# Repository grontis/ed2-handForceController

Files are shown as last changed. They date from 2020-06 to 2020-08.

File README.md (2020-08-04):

# ed2-handForceController
Engineering Design 1/2 Project for Group 9

TeamMembers:

Lillian Boettcher

Grant Kveton

Dhaval Manojkumar Shirvi

### Final Presentation Video
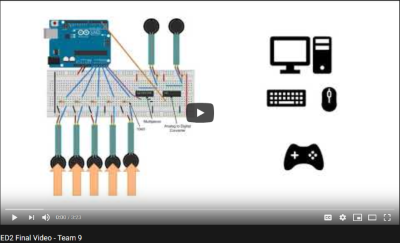
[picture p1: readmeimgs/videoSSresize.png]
finalVideo (http://www.youtube.com/watch?v=HQArYuJmiJw "ED2 Final Video - Team 9")


## HFController.cs documentation
*(as of 7/29/20, gkveton)*

#### Constructors:
HFController() - Initializes a new instance of the HFController class

#### Fields:
serialPort - System.IO.Ports.SerialPort object

serialMessage - incoming message form serial port

NUMBER_OF_SENSORS - number of sensors being read

readings - array containing sensor readings

#### Properties

IsConnected - Gets the boolean value of whether the serial port is open and connected for the device.

PortNames - Gets the array of string values for all available port names.

ConnectedPortName - Gets the string value of the port name being used for serial communication. 

#### Methods:
GetSensorValue(int sensorId) - returns sensor reading from given sensor number. 

PrintReadings() - Debugging method used to print array of readings.

ReconnectDevice() - Runs the port finding and connection algorithm.

ClosePort() - Closes the connection to the serial port for the device.

##### Example use
```
using System.Collections;
using System.Collections.Generic;
using UnityEngine;

public class CubeController : MonoBehaviour
{
    private HFController controllerInput;   
    
    // Start is called before the first frame update
    void Start()
    {
        controllerInput = new HFController();
    }

    // Update is called once per frame
    void Update()
    {
        if(controllerInput.IsConnected)
        {
            ProcessMovement();
            controllerInput.PrintReadings();
        }
        else
        {
            Debug.Log("Controller not connected");
            controllerInput.ReconnectDevice();
        }

    }
    
    private void ProcessMovement()
    {
        if (controllerInput.GetSensorValue(0) > 800)
        {
            transform.position = transform.position + new Vector3(5f * Time.deltaTime, 0, 0);
        }
        if (controllerInput.GetSensorValue(1) > 800)
        {
            cube1.transform.position = cube1.transform.position - new Vector3(5f * Time.deltaTime, 0, 0);
        }
    }
    
    private void EndSimulation
    {
        //Application exit logic here, perhaps this function is called when an "Exit" button is clicked. 
        controllerInput.ClosePort();
    }
}
```

## Serial Communication Between Arduino and Unity C# 
*(as of 7/31/20, gkveton)*

If you do not have Unity installed, install it (The unity hub is a nice way to keep track of projects and install versions, in my opinion):
https://unity3d.com/get-unity/download

If you do not have the Arduino IDE installed, install it:
https://www.arduino.cc/en/main/software

Connect force sensors and Arduino based on circuit diagram:
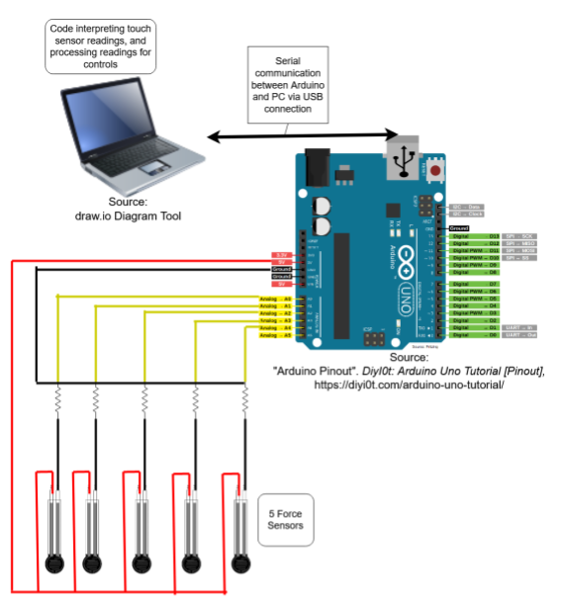
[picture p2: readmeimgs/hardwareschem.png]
proposal_hardware_schematic


Clone the project repository to your local machine:
https://github.com/grontis/ed2-handForceController

Open the "main" Arduino sketch in the Arduino IDE and upload the sketch to the Arduino:
File-> Open -> Navigate to the arduino/main folder in the cloned repo and open the Arduino file.
Make sure your Arduino is connected to USB of computer.
Sketch->Upload 
(You may need to check that your serial port for the Arduino is selected in the IDE correctly, this can be done under Tools->Port:… mine has an option for COM3(Arduino Uno))

Open the Unity project and run it to test communication:
Open the UnityHub, click “Add” and navigate to the cloned repo and select the “ed2-UnityProject” folder and click “select folder”. It is possible you may encounter that you do not have the project’s version of unity installed. If so you can click on “Installs” and install the version listed under the project (it will probably be best for us all to be working on the project in the same version since we are sharing the repository).
Open the project and in the project window in assets in the “Scenes” folder. Double click to open the “grant_3dobject_test”

This test scene involves moving 5 cubes based on 5 sensor values. Make sure that the value for NUM_OF_SENSORS is set to the correct number of sensors being used in both the HFController.cs script and the main arduino sketch.

press the play button (or CTRL+P) to start the application.
Once the scene is started in the Unity editor the script will programmatically attempt to connect to the Arduino and establish communication. This is done by sending a "wakeup" message to each of the available serial ports in the system. The main arduino sketch is programmed to await the "wakeup" message and will send a response when received. There is a mechanism of callbacks between the arduino and the software as data is transmitted. 

NOTE: When making a new Unity project (that isn’t the one setup in the repo) that will be using serial port communication, *before* creating your C# scripts you have to go into Edit-> Project Settings-> Player -> Api compatibility level and set it to “.NET 4.x”, and then restart Unity. Otherwise, the System.IO.Ports namespace will not import. From my debugging over this, I think it has something to do with the way Unity creates C# script assemblies.

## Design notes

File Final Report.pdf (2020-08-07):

1

## Hand Force Controller

A force sensing gaming and computer controller

A Proposal Submitted by Team 9

Lillian Boettcher

Grant Kveton

Dhaval Manojkumar Shirvi

Affiliations

Florida Atlantic University

Department of Engineering and Computer Science

Course: ENG 4952C - 001

Instructor: Dr. Hari Kalva

Submitted 6 August 2020

Hand Force Controller | Boettcher, Kveton, Shirvi 2

### Project Summary

Accessibility to computer functionality, gaming, and virtual reality is becoming more

demanding as technology advances further and more people are using these devices and

technologies. Many devices exist for controlling computer and game commands, most popularly

a computer keyboard and mouse as well as certain specialized gaming controllers. For virtual

reality, controllers are moved in real life and translate to movements in a virtual space using

internal accelerometers and gyroscopes. These have limitations for some individuals, primarily

in how they often require excessive movement. There are some controllers made for people who

have difficulty moving their hands or limbs effectively enough to use these devices, but they

normally consist of additional buttons and still require a large level of movement.

The Hand Force Controller is a proposed device to solve this problem by using force

sensors to read subtle amounts of force in a user’s fingertips and throughout their hand. The

force needed to use the controller can be specified through user calibration. Additionally, the

sensors can be moved around to however the user finds them most comfortable. Therefore, the

Hand Force Controller is a stationary controller that can be specialized to how the user wants the

layout and how much force they want to apply in order to use it. The controller comes with an

application that is straightforward to use, a 3D printable platform that can be customized to the

user’s preferences, and a user manual. The software application has quick calibration settings

and a simple interface for accessing other functionality. To demonstrate how it can be used in

gaming and virtual reality, there are two game demos, a first-person shooter game and a playable

virtual piano. As part of the main functionality, there is a program for setting different controller

gestures to different keyboard commands so the controller can emulate any computer game.

Thus, the Hand Force Controller is a combination of hardware and software to present a

specialized gaming controller and keyboard emulator.

(Boettcher)

### Table of Contents

Project Summary | 2
Introduction | 7
Background | 7
Problem Statement | 8
Scope of Work | 9
Overview | 9
Design Stage | 9
Hardware Implementation Stage | 9
Software Implementation Stage | 10
Final Interface Implementation and Testing | 11
Literature Review | 11
Alternative Solutions | 14
Evaluation | 16
Decision | 16
Problem Implementation Plan | 18
Research | 18
Design | 18
Image 1: Platform Model with Combined Components | 19
Deliverables | 20
Tasks | 21
Figure 1: Task Division Diagram | 23
Prototype Construction | 23
Image 2: Hardware Prototype | 24

Implementation Details | 25
System Specifications and Functionality | 25
System Design | 26
Figure 2: Overall System Design Diagram | 27
Hardware Subsystem Design | 27
Figure 3: Circuit Diagram | 29
Serial Communication Subsystem Design | 29
Figure 4: HFController Variables and Functions | 31
Piano Simulation Subsystem Design | 31
Image 3: Piano Simulation View | 32
Figure 5: Piano Simulation Use-Case Diagram | 34
Keyboard Emulation Subsystem Design | 34
Image 4: Keyboard Emulation Settings | 35
Figure 6: Keyboard Emulation Use-Case Diagram | 36
First-Person Shooter Game Subsystem Design | 36
Image 5: First-Person Shooter View | 37
Figure 7: First-Person Shooter Game Use-Case Diagram | 38
Testing Results | 38
Table 1: Serial Communication Testing Outline | 39
Discussion on Lessons Learned | 40
Conclusion | 42
References | 43
Organization Chart | 45
Figure 8: Organization Chart | 45
Budget | 46

Table 2: Projet Budget | 46
Appendices | 47
Hardware Schematics | 47
Figure 9: Circuit Diagram | 47
Program Schematics | 48
Figure 10: Serial Communication Pseudocode Schematic | 48
Figure 11: Application Main Screen UI Design | 49
Figure 12: Calibration Activity Diagram | 49
Figure 13: Keyboard Emulation Activity Diagram | 50
Figure 14: Piano Simulation Activity Diagram | 50
Figure 15: First-Person Shooter Game Activity Diagram | 51

### Introduction

Background

Controlling computer software originally uses a simple keyboard and mouse to maneuver

selecting system objects and typing documents and commands. However, with an increase in the

complexity of computer gaming and virtual reality (VR), specialized computer controllers are

now often used for different games with different playstyles. These controllers require the user’s

hands to be in different positions and perform different positions. Many controllers use large

movements of joysticks or the controllers themselves through motion sensing, which can allow

for more immersive experiences or more possible ways to control game actions.

These controllers vary greatly and are continuously in demand as the number of people

who play games and perform various computerized tasks increases and as controller and game

technology advances. These controllers are mainly geared towards people who are passionate

towards gaming and VR and want more immersive or specialized control in their games or

simulations. However, some controllers exist for people with disabilities, such as a loss of limbs

or trouble with movement, which allows people with physical disorders to control computer

commands and participate in gaming.

(Boettcher)

Problem Statement

While there are some gaming controllers for people who have physical disabilities, they

are primarily geared towards people who have amputated limbs or distorted figures. There are few controllers for people who have trouble with simple movements, such as rapidly moving

their fingers up and down, which is required on nearly all types of gaming devices. For virtual

reality in particular, there is little in the way of controllers that do not require large limb

movements, since VR uses movements in real life to translate to movements in a virtual

environment. Because of this, controllers do not largely exist for VR for disabled people who

cannot move well enough to use VR controllers and equipment. Therefore, while there are

people who need special devices for playing computer games without having to perform

excessive movements, especially for VR simulations, there are few controllers that have proven

effective enough to be a solution for these individuals.

(Boettcher)

### Scope of Work

Overview

### 1. Design Stage

The Hand Force Controller begins with an initial design stage that involves researching

what components will be needed to accomplish the goals of the initial idea. The design stage

proved to be an iterative process as the team finalized the system requirements in the original

proposal document and determined what components would be best suited for the project. The

initial hardware design involves developing circuit diagrams based on research, so the

components can be quickly assembled and tested when received. Software libraries and tools are

researched in this stage to determine a practical design and implementation of the desired

software applications to be delivered with the controller. The list of hardware components is

finalized for the project budget and confirmed to be ordered.

(Kveton)

### 2. Hardware Implementation Stage

The hardware implementation stage begins once the hardware components have been

ordered and received. The hardware implementation takes a bottom-up approach in that the

complexity of the project increases as more components are implemented and tested. The first

stage involves configuring a single sensor and having values read by the Arduino

microcontroller. The second stage involves configuring multiple sensors to be read by the

Arduino. The final stage of the hardware implementation occurs when the number of sensors exceeds the number of analog inputs available on the Arduino microcontroller. A multiplexer is

implemented in this final stage to allow for a greater number of sensors to be used.

(Kveton)

### 3. Software Implementation Stage

The first stage of the software implementation is the programming and testing of serial

communication between the Arduino microcontroller and the computer running the applications

created in Unity. Similar to the hardware implementation, this stage takes a bottom-up approach

by iteratively introducing and testing new components. First, the communication between

devices is tested without using any sensors. Once the communication is established, the system

for transmitting the sensor data can be implemented. The other software applications in the

project are heavily dependent on this component. Therefore, testing various use cases and

handling errors is very important.

The second stage of the software implementation involves programming the three demo

simulations that are used to demonstrate the Hand Force Controller’s capabilities. These three

applications have been divided up between the team such that each team member has an

application to work on. The keyboard command simulation and the piano simulation were

decided upon in the early design stages for the project. The idea to include a demo video game

was decided upon later in the project during progress update discussions with the professor.

Another aspect of this stage in the software implementation is the sensor calibration system. This

is designed to be implemented in a way such that it can be used in the demo applications.

(Kveton)

### 4. Final Interface Implementation and Testing

Once each of the software subsystems have been implemented and tested on their own,

they are connected together by an interface within one Unity project. This stage also involves

final testing of the entire system with all of the subsystems connected to the main screen

interface. The development testing of each subsystem on their own should allow for simplified

integration into the main system interface.

(Kveton)

Literature Review

Team Member Reviewing: Lillian Boettcher

Title: “The Human Controller: Usability and Accessibility in Video Game Interfaces”

This paper focuses on analyzing current availability of accessibility in gaming controllers

and why there is a need for an increase in accessibility. It addresses an initial fact that there are

concerns, such as cost concerns, related to providing accessibility and having all controllers

require a large amount of accessibility is not practical or feasible. Despite this, it points out that

there is an existing demand for accessible controllers and that there are people who develop

disorders, including gamers, as they age or go through life, covering aspects of the demand. It

evaluates case studies to determine possible strategies for going about creating accessibility in

places where it is lacking.

The ideas on how to improve upon current lacking technologies for the physically

impaired gives insight into specific tasks our project should accomplish. More specifically, it

stresses that there is little in the way of easy to use controllers for the physically disabled. These constraints would need to be met by creating a device that requires minimal movement and

difficult performing any required movements, which is the key focus of this project.

Team Member Reviewing: Lillian Boettcher

Title: “Game Not Over: Accessibility Issues in Video Games”

This paper covers the scope of which accessibility for games is in demand. It covers both

physical and mental aspects of where games may lack accessibility, from not providing subtitles

to follow along to audio to not being able to use the controllers that a game console requires.

These issues stem from disabilities in four different categories: visual disabilities, auditory

disabilities, mobility disabilities, and cognitive disabilities.

The Hand Force Controller relates to the third addressed disability category: mobility

disabilities. It supports the need for accessibility controllers by relaying statistics on how 12.1%

percent of the population has some sort of mobility disability. It also addresses that there are

individuals who may play games and want to continue after receiving these abilities from aging

or injury, the most common causes of these types of disorders, further proving the presence that

this is a problem with a demand for a solution.

Team Member Reviewing: Grant Kveton

Title: HandNavigator: “Hands-on Interaction for Desktop Virtual Reality”

This paper presents an innovative interactive system for controlling digital models using

hand gestures. The physical interaction device is utilizing force sensors to measure finger and

palm gestures which are then translated into software actions, similar to the Hand Force

Controller. The physical interaction device uses forces exerted from the palm and fingers to

control a virtual hand model, rather than measuring real hand movements and gestures. The

paper discusses the necessity of implementing plausible real-time interactions with the virtual

hand to enhance the user’s immersion. This is done by correctly mapping the physical device to a

well designed virtual hand model. Visual feedback, when done properly, can give the user the

perception that they are actually touching virtual objects.

Team Member Reviewing: Grant Kveton

Title: “Game Console Controller Interface for People with Disability”

This paper proposes an interface device to allow people with upper limb disabilities to

play console video games. Currently, there are few devices that address the difficulties disabled

users encounter when attempting to play video games. As video games have become more

complex, the more challenging it has become for users with disabilities to play using traditional

controllers. The device introduced in the paper seeks to implement an entirely new interface

device that uses off-the-shelf sensors and switches that can be used by disabled users to play

video games on a traditional console. The paper also describes the implementation of a method

for the user to customize the mapping of sensors to joypad pushbuttons, a similar feature to the

Hand Force Controller’s custom keyboard input subsystem. Another similar system requirement

to the Hand Force Controller is that the interface device must allow a simple setup procedure,

allowing the user to utilize the device with various applications.

Team Member Reviewing: Dhaval Manojkumar Shirvi

Title: “Evolution of Game Controllers: Toward the Support of Gamers with Physical

Disabilities”

This paper focuses on the limited consideration for players with physical disability

throughout the evolution of game controllers. It covers the disadvantage the gamers with

physical disability such as limited mobility, dexterity or a missing limb or part of the limb have

when using the standard controllers. It also covers some of the modified controllers that reduces

the disadvantage on the physically disabled players. However, the modified controllers are made

considering the players with a missing limb.

The Hand Force Controller answers the issue for the players with limited mobility or

dexterity. The controller was designed considering the players with limited mobility. And since,

the controller does not require hand movement except for exerting slight pressure, it could be a

potential solution for players with limited mobility or dexterity.

Alternative Solutions

There are many alternative approaches to VR controllers but there are not many that

require minimal movement. Currently many VR technologies use touch sensors in their

controllers. Most touch sensors use digital output, which is high if touched or low if not.

However, some touch sensors have the capability to output analog value. Even so, the VR touch

sensor controllers require hand movement. Another alternative to force sensors could be flex

sensors. The flex sensors measure the deflection or bending, which can be one of the most effective sensors for the immersive VR experience. The flex sensor might be a good approach for

immersive VR controllers, but it still requires hand movement. Although, it might not require as

much movement as touch sensors.

One of the most important hardware components is the microcontroller board. A

microcontroller board reads the values from the sensors and sends it to the computer. There are

many Arduino boards that have the same functionality, such as Arduino Leonardo and Arduino

micro. Arduino Leonardo and micro are also compatible with the keyboard library of the

Arduino. Arduino Leonardo and micro boards come with 12 analog pins (Arduino). However,

both boards are a bit advanced for beginners.

For the software aspect, creating an application for the user to test the functionality of the

controller, can be achieved on almost any platform. For example, the unreal engine by epic

games and using python executable directly. The unreal engine uses C++ scripts for the

applications, which has a method to simulate a key press. The unreal engine also provides high

quality visuals (Unreal Engine). Although the keyboard simulation only works on Windows OS

and unreal engine requires a high powered PC to run the applications due to the high-quality

visuals. On the other end python has the keyboard library and can also be used to create an

application for the user (Python). However, the application would not be very user friendly.

(Shirvi)

Evaluation

The main concept behind the Hand Force Controller is to minimize the hand movement

of the user while performing in-game actions. The force sensors have great potential to achieve

the goal, since it only requires for the user to exert a small amount of pressure. The other sensors

such as touch and the flex sensors require some hand movement to perform actions. Therefore,

the force sensor is a more preferable choice, since it requires the least amount of movement of all

the three sensors. The Arduino Uno is the base model of some of the other Arduino boards.

Arduino uno in comparison to Arduino Leonardo and Arduino micro, has less functionality but

Arduino Uno is more beginner friendly than the other two boards. Even though Unity might not

have high quality visuals or a keyboard simulation functionality, it would be the best choice for

making a user friendly application which can be run on a low end PC. And to achieve the

keyboard simulation functionality, ironpython can be used to execute python commands from cs

script. Therefore, unity makes an ideal choice for this project.

(Shirvi)

Decision

Many physically challenged could benefit from a new type of controller with another

level in how easy it is to use. To make an effective controller that allows individuals who are

physically disabled, the main factor requirements the controller needs is ease of use by

minimizing required movement. This could be done by using force sensors to detect small and

weak amounts of pressure in a user’s hand, which could be customly placed around an

individual’s hand. Additionally, to maximize accessibility, it should be held in an open-source repository that developers and users can easily access, have an adjustable platform and

calibration, and have clear instructions and examples on how to use it.

(Boettcher)

### Problem Implementation Plan

Research

The Arduino programming documentation was researched during the early stages of

design and implementation to design software functionality necessary for meeting the functional

requirements (Arduino). The analogRead() function allows the Arduino sketch to read values

from the analog force sensors connected to the analog input pins. The Serial object contains

functions related to the implementation of the serial communication, such as the println()

function and the readStringUntil() function.

The official C# documentation from Microsoft was researched during the early stages of

design and implementation to design software functionality for serial communication in Unity

(Microsoft). Specifically, the SerialPort class in the System.IO.Ports namespace was researched.

Similar to the Arduino Serial object, this class includes functions for opening the serial port

connection, reading from the serial port buffer, and writing to the serial port buffer. Code

examples in the documentation were studied for understanding of the SerialPort class but were

not used in the implementation of the project.

(Kveton)

Design

The initial design of the project included an Arduino Uno for utilizing five force sensors,

one for each finger. The design was later changed to incorporate three more force sensors. Since

the Arduino Uno only has six analog input pins, a multiplexer chip was added for the extra sensors to connect to the Arduino. This design increases the ability of the Hand Force Controller

to take into account a majority of basic hand movements. The first five force sensors are for each

finger and the extra three force sensors are for the palm, the left palm, the right palm and the

back of the hand. These sensors are to be placed on an adjustable platform comfortably position

the sensors around the user’s hand.

The platform design involves three components: the finger and thumb components, which

are used for resting the finger and thumb while using the controller, and a base. Each finger rests

on four finger components and the thumb component is used for the thumb. As the finger and

thumb components are used for resting fingers and thumb, the base platform can be used to rest

the palm of the user’s hand. The base platform has space underneath it, for placing the Arduino

Uno, and has space for force sensors to rest on the finger and thumb components. The finger and

thumb components also have slits for the force sensor wires to pass through and be placed on top

of the components so that the wires can be out of the way of the user’s fingers.

Image 1: Platform Model with Combined Components

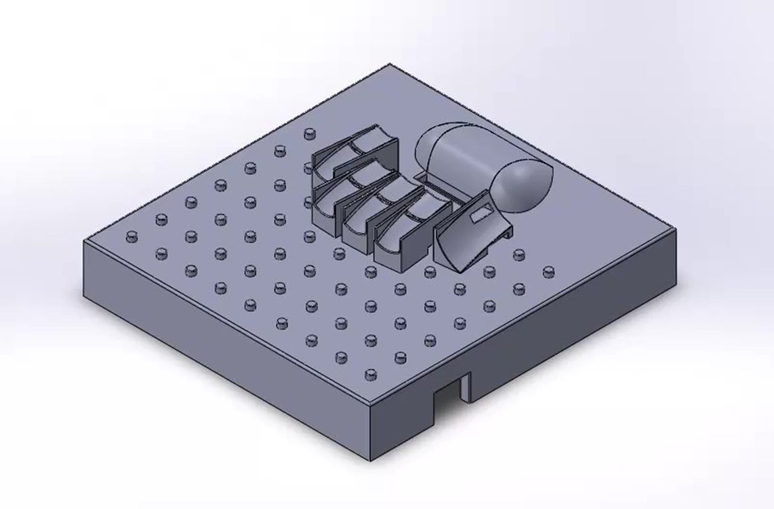
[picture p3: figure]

The Hand Force Controller can be tested on its application, which includes calibration

settings, a piano simulation, a keyboard emulator, and a first person shooter game. In the piano simulation, the Hand Force Controller can be used to play piano in a top view. The piano

simulation can be converted to VR simulation by connecting a VR headset to the camera display.

The keyboard emulator enables the Hand Force Controller to emulate keyboard keys and

commands. This allows the user to use the Hand Force Controller on any application. The first

person shooter game can be used to test the Hand Force Controller’s ability to play a common

style of computer game.

(Shirvi)

Deliverables

The project deliverables include:

- The Application
- Calibration
- The Piano Simulation
- The Keyboard Emulator
- First Person Shooter game
- Printable 3D modeled platform
- Base platform
- Finger component
- Thumb component
- Instruction manual
- Repository for the deliverables
- Hardware design

The application includes the piano simulation, the keyboard emulator and the first person

shooter that demonstrates different functionalities of the Hand Force Controller. The 3D modeled

platform includes three components one is the base platform, one is finger and the last one is

thumb. The instruction manual is a detailed step by step guide for assembling the hardware and

the 3D modeled platform. The manual also includes a guide for using the application. The

repository is for development purposes and to download the application, printable 3D platform

and the instruction manual. The hardware components include all the hardware components

required for assembling the Hand Force Controller.

(Shirvi)

Tasks

The project was given tasks that are designed to finish the project with all of the

functional and nonfunctional requirements. The simplified task division is listed below in a

diagram. These tasks were originally made to allow us to divide the work between group

members and calculate how much work we have done and how much we had left. The following

is a list of tasks and the team member leading in completing the task:

- Gather all hardware components (all)
- Design hardware (all)
- Manage an accessible repository for the application, code, and development materials

(Kveton)

- Create a user manual that gives instructions on how to use the Hand Force Controller and

replicate our work (Boettcher)

- Model components for a 3D printable platform (Shirvi)
- Main application:
- Create a main application display (Boettcher)
- Create calibration system (Boettcher)
- Create navigation to other parts of software (Boettcher)
- Consolidate all parts of the application and deploy as executable (Kveton)
- Keyboard emulator (Shirvi):
- Create a UI for emulation settings (Shirvi)
- Create script for saving emulation settings on play (Shirvi)
- Program active emulation script in Python using saved settings (Shirvi)
- Program Python receiving of sensor values from Arduino (Kveton)
- Piano simulation (Boettcher):
- Model a 3D piano asset (Boettcher)
- Connect audio files to piano keys (Boettcher)
- Script piano playing functionality based on saved calibration (Boettcher)
- First-Person Shooter Game (Kveton):
- Gather assets to form game scene (Kveton)
- Program player movement and actions based on calibration and HFController

settings (Kveton)

- Program enemy intelligence (Kveton)
- Program health and ammo systems (Kveton)

(Boettcher)

Figure 1: Task Division Diagram

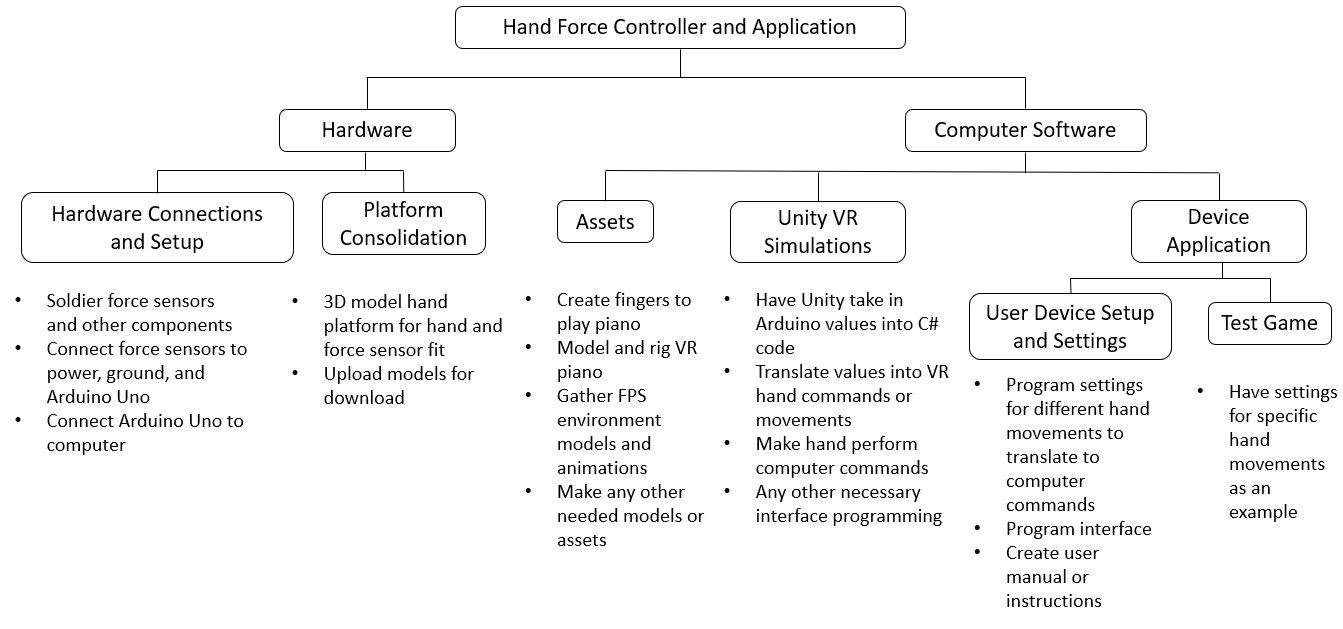
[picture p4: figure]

Prototype Construction

The complete initial prototype consists of eight force sensors to portray the complete

functionality. However, the 3D modeled platform is not a necessity for playing the simulations

created, calibration, or using the Hand Force Controller as a keyboard emulator. Therefore, the

platform was not printed and used for the initial prototype.

The initial prototype uses a running Arduino with a USB cable to print to a computer.

The model could be made using another form of connection, however, such as a Bluetooth

adapter. All eight force sensors are connected to the five-volt power supply from the Arduino

and a ground. Before the ground, however, there is a resistor for each sensor in order to allow

the sensors to read the pins. The initial prototype uses 10 kilo ohm resistors for the specific

sensors used in the prototype, but the design allows for other types of force sensors, which may

require different level resistors. In order to increase the analog inputs in the Arduino Uno, a

multiplexer is used. This is gone into more detail in the hardware section.

The prototype had no issues in terms of calibration, lag, or other common problems

known with prototypes. For future modifications in improving the Hand Force Controller, more

force sensors can be added for more control over software and allowing more possible gestures.

In addition, more platform models could be made to be more effective for different individuals

and possibly easier assembly. Parts could also be more specialized; the jumpers used in the

prototype make it different to consolidate the hardware and better hardware components could

probably be found.

(Boettcher)

Image 2: Hardware Prototype

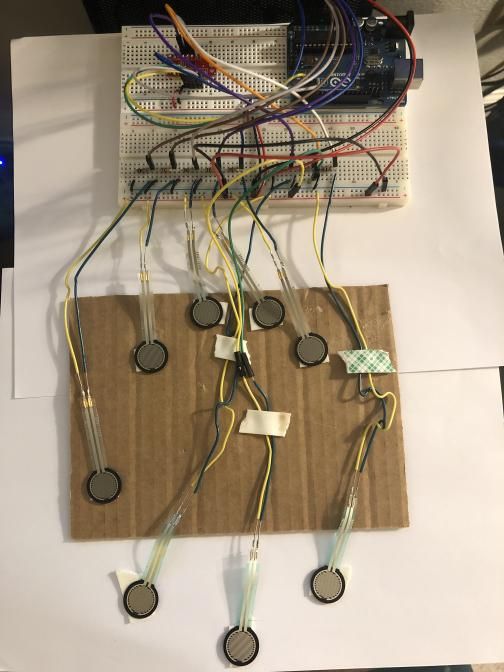
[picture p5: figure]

### Implementation Details

System Specifications and Functionality

The original functional and non-functional requirements were all generally met at the

conclusion of the project. There were no requirements officially added to the project, but the

project came to have more of a focus on also demonstrating more capabilities of the Hand Force

Controller, meaning the first non-functional requirement became more significant as

demonstrating the controller’s use became an important part of the project.

Functional Requirements

1. The system shall measure the force exerted by each finger of a human hand as an

increasing or decreasing analog value.

2. The system shall quickly and accurately transfer analog data from an Arduino

microcontroller to a computer.

3. The system shall be able to translate different analog inputs into different computer

keyboard commands.

4. The system shall be able to recognize different finger force patterns to translate into

commands or actions.

5. The system shall be implemented in such a way that there are minimal dependencies

required during setup when using the controller for different applications.

6. The physical platform for the controller shall include design and functionality that

accounts for varying hand sizes between users.

Nonfunctional Requirements

1. The product shall include an application for users to test the product.
2. The product shall include a manual or guideline for users.

(Boettcher, Kveton)

System Design

The overall system can be divided into two categories: a hardware subsystem and a

software system. The hardware system forms the Arduino Uno, force sensors, and their

hardware connections. The software consists of a Github repository containing a user manual,

3D model platform components for 3D printing, and an application. The Hand Force Controller

application can be divided into four parts: the main screen, which is where calibration and scene

navigation takes place, a keyboard emulator, a piano simulation, and a first-person shooter game.

(Boettcher)

Figure 2: Overall System Design Diagram

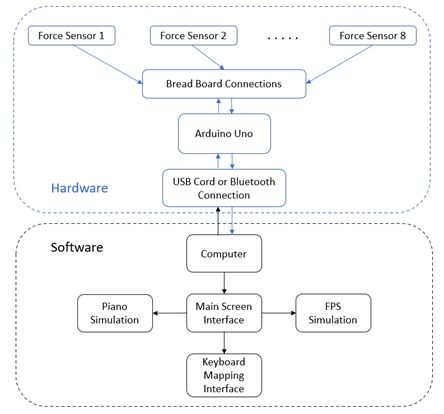
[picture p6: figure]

Hardware Subsystem Design

The microcontroller used in this project is the Arduino Uno Rev3 model. The project uses

all six analog inputs for the purpose of reading sensor input data. Five analog inputs are directly

connected to force sensors. The remaining analog input is connected to the common output pin

of the multiplexer. Three of the digital pins are connected to the select pins of the multiplexer

and are set to output values for determining which individual input pin of the multiplexer is to be

read from. The Arduino microcontroller has a USB type B port where the Arduino is connected

to a PC via USB cable, and this port is the connection in which the serial data communication

occurs.

Force Sensitive Resistors (FSR) are thin sensors that detect physical pressure upon the

sensor. As one applies pressure to the force sensor the resistance goes down and a measurement is given based on the change in resistance (Adafruit). The range of values for the force sensors in

this project was from 0 to about 1000, with 0 representing no force applied and 1000

representing a large amount of force applied.

Due to the limitations of the Arduino’s amount of analog input pins, it was necessary to

implement a multiplexer into the hardware design once the project began using more than six

force sensors. The multiplexer used in this project is the 74HC4051 eight-channel multiplexer

breakout. A multiplexer is able to iterate over its individual input pins by using three “select”

pins to determine which pin’s data will be output. The “select” pins are connected to the digital

output pins of the Arduino. The multiplexer has 8 individual input pins, and these are selected by

outputting their corresponding binary values to the “select” pins. For example, if the input pin Y1

is to be selected, then the digital pins would output “LOW, LOW, HIGH” which could also be

interpreted as the binary value 001 . The multiplexer has a common output pin that is connected

to an analog input pin of the Arduino where the currently selected input’s data is sent (SparkFun

Electronics).

(Kveton)

Figure 3: Circuit Diagram

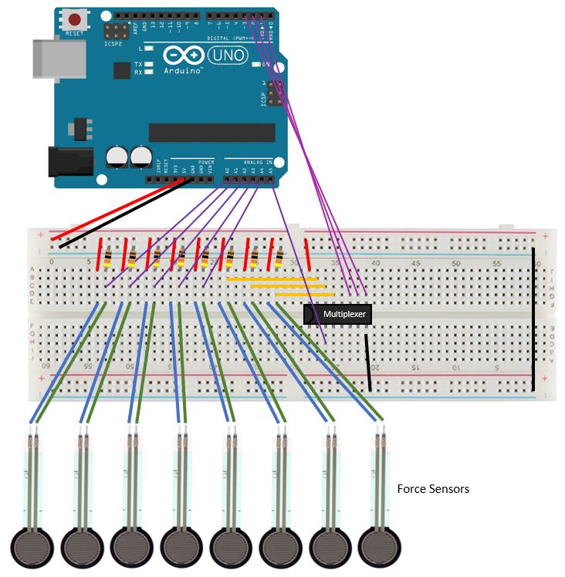
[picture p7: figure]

Serial Communication Subsystem Design

The Arduino microcontroller writes data being read from the force sensors to a serial port

buffer. A C# class in the Unity game engine, called HFController, then reads the incoming data

from the serial port buffer. This system was first implemented and tested by writing dummy data

to the serial port to be read by the HFController class on the receiving computer. Once the

communication had been established and tested, the sensor data could be used in communication.

The sensor readings for each loop within the Arduino code were packaged in a data structure of

comma separated values. The packets of readings were then written to the serial port buffer. The

packet data structure required a parsing algorithm to be designed within the C# code to unpack

the string of comma separated values to be stored in a local array. A public method for the

HFController class, GetSensorValue(int sensorId), was developed to return the current reading

for a given sensor number.

In the early stages of development, the port name was hardcoded into the Unity C# code.

An issue with this implementation is that various machines may have differently named serial

ports when the Arduino is connected to the PC. An algorithm was developed to iterate between

all available ports on the computer, sending a “wake up” message to the port. The Arduino code

is configured to wait for the “wake up” message and will send a response message when it is

received. When the C# code receives the response, it will keep that port open for communication.

There is also a timeout mechanism in place so that the Arduino will go back to its sleep state,

awaiting the “wake up” message, if it does not receive a “reading” message from the serial port

after the timeout value has passed. In the later stages of development, a public method for the

HFController class, ClosePort(), was needed to close ports as the main interface switched

between demo applications. The HFController class and the Arduino sketch are programmed

such that only the NUM_OF_SENSORS constant needs to be changed when adding more

sensors to the system.

The HFController C# class is designed in such a way that it abstracts the serial

communication and can be used modularly within various applications. The figure below shows

the fields, properties, and methods for the HFController class. The class is also documented in

greater detail in the readme of the project’s GitHub repository.

(Kveton)

Figure 4: HFController Class Variables and Functions

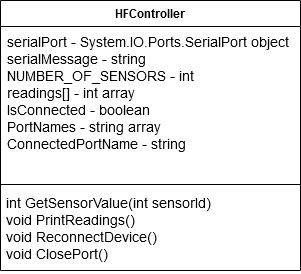
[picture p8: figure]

Piano Simulation Subsystem Design

The piano simulation is designed to demonstrate the functionality of the Hand Force

Controller to work for playing a computer simulation or virtual reality game. The game can

simply be played in a first-person view, with the camera at an orthogonal top view, but the

camera view can be adjusted to be controlled in respect to a VR headset, turning it into a VR

simulation.

The simulation is played using all eight of the force sensors. The first five force sensors

(sensors 0-4) correspond to the first five fingers of the human hand. The controller only has a

single hand and uses differently colored capsule models to represent fingers that can press keys,

so the user can use their right or left hand to control the virtual fingers. Therefore, the fingers are

referred to by number and color instead of the name of the finger, with finger 1 colored red, finger 2 colored orange, finger 3 colored yellow, finger 4 colored green, and finger 5 colored

blue.

Image 3: Piano Simulation View

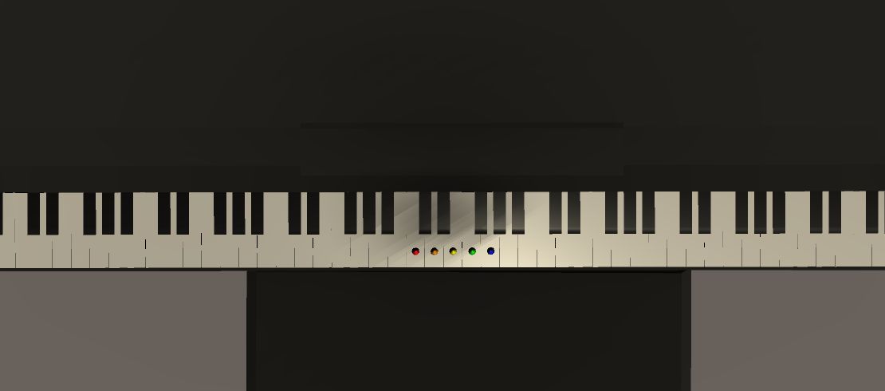
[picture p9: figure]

Force sensors 5 and 6 control the left and right movement of the fingers, respectively.

The last force sensor, sensor 7, is used to move the fingers forward towards the black keys on the

piano. Keys are pressed by pressing the first five force sensors. The amount of force needed to

press the notes for each finger is defined by the calibration in the previous main screen. This

also applies to the amount of force to activate left, right, and forward movement for the

remaining three sensors.

Key pressing is recognized by the location of each finger. For each finger, the simulation

programming checks for the position of the finger. The x and z coordinates give the position of

the keys, which are saved in array variables. These coordinates are checked for each finger,

which defines what key can be pressed. The value of the finger force sensors define the y

coordinate position of the fingers. If the finger is lowered to a certain degree, the note at its

position is activated. An activated note changes color and plays its corresponding audio file. A

white note will change to pink while activate and black notes to purple. When the position of the finger changes to a different note through a change in the x or z coordinates or when the y

coordinates are raised above a certain threshold, the note audio that was previously playing stops.

The x coordinates of all of the fingers, as well as the camera, are changed using sensors 5

and 6. When sensor 5 is pressed to a value above its calibration value, each finger and the

camera move left, or across the negative x-axis, a specific degree each frame update. The

amount is defined by the degree to which the sensor value is greater than the calibration value.

The same applies to force sensor 6, except it creates right movement when pressed across the

positive x-axis.

Force sensor 7 moves all of the fingers forward on the z-axis, which allows the black

keys to be playable. When the sensor value is above the calibration value for sensor 7, the

fingers all move forward. The amount moved per frame is, like with the left and right

movements, defined by the amount the sensor value is larger than the calibration value. When

the sensor value is lower than the calibration value, the fingers move backwards towards the

white key only region (where black keys cannot be reached or played along the x-axis).

(Boettcher)

Figure 5: Piano Simulation Use-Case Diagram

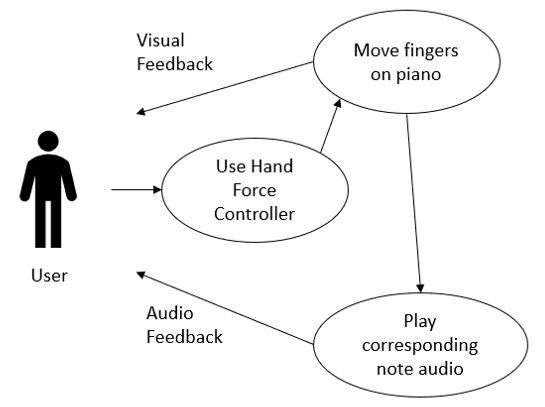
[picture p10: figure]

Keyboard Emulation Subsystem Design

The keyboard emulation program is designed to turn the Hand Force Controller into an

emulator for any computer application. The main purpose of the keyboard emulation subsystem

is to be able use the Hand Force Controller to play different video games, though it can be used

on other applications as well.

The keyboard emulation program uses different gestures that can be performed on the

Hand Force Controller to emulate different keyboard commands. The gestures include the

individual eight force sensors and combinations of the first five force sensors. All the gestures

are available to be viewed on the keyboard command screen. The gestures are simple and self

explanatory. Eight of the available gestures correspond to the eight force sensors. The

combination of the first five force sensors (for each finger) can be used for combinational

gestures. A key or a command can be assigned to each available gesture on the keyboard

command screen. It is mandatory to assign keys to the eight individual gestures, however assigning a key to the combinational gestures is optional. A play button can be pressed when the

user is done assigning the keys or gestures.

Image 4: Keyboard Emulation Settings

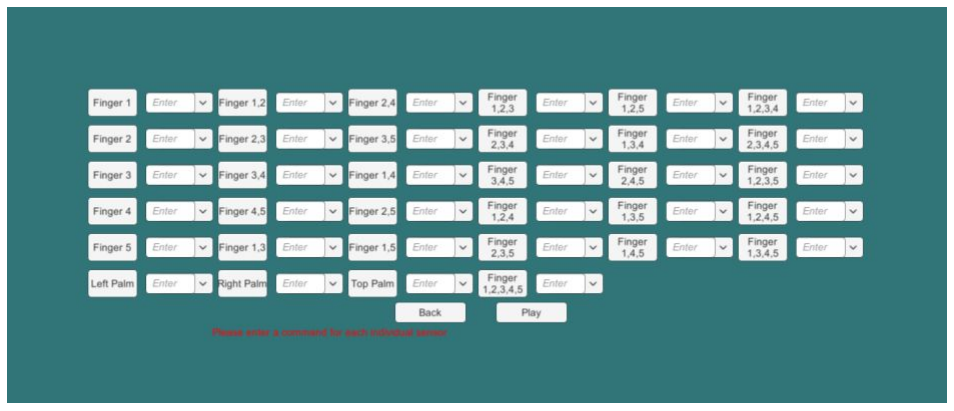
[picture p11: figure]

Once the play button is clicked, the assigned keys and the port name are saved to a text

file and a Python script is executed using IronPython. IronPython allows C sharp scripts to

execute or use Python commands. The Python script reads the keys and the port name from the

text file using an open() function. The port name is then used to connect to the Arduino via a

serial library. The Python script also uses the keyboard library to simulate key pressing. The keys

read from the file are used by the keyboard.press() function, which performs key presses. The

values of the force sensors are constantly being read in a main loop from the Arduino by the

Python serial library. Every time one of the gestures is performed on the controller and the

reading is above a certain threshold, based on saved calibration values, the key assigned to each

respective gesture is pressed.

(Shirvi)

Figure 6: Keyboard Command Use-Case Diagram

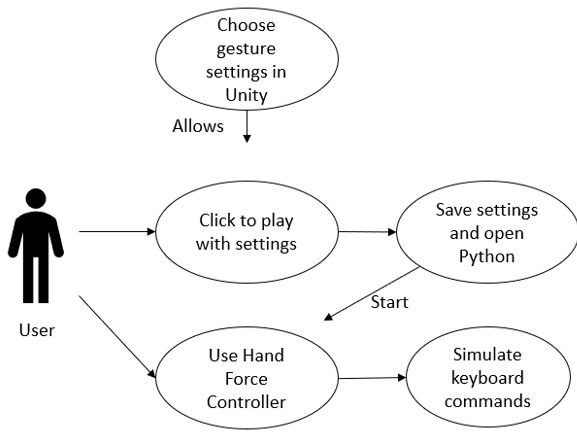
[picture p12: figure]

First-Person Shooter Game Subsystem Design

In the early stages of design and implementation, it was suggested to the team by the

professor that an open source video game would be an interesting and effective way to

demonstrate the capabilities of the Hand Force Controller. A team member was currently

working on an online tutorial course for game development in Unity that could be used as an

example application (Tristem and Davidson). A video game developed within the team was

beneficial to the project’s time scope because the source code was more familiar compared to an

unfamiliar open source project. The zombie first person shooter (FPS) game was developed in

this tutorial course and used free art assets provided with the course and from the Unity asset

store. The integration of the Hand Force Controller into this demo game is an example of the

Hand Force Controller being implemented directly into a video game by the developer.

Image 5: First-Person Shooter View

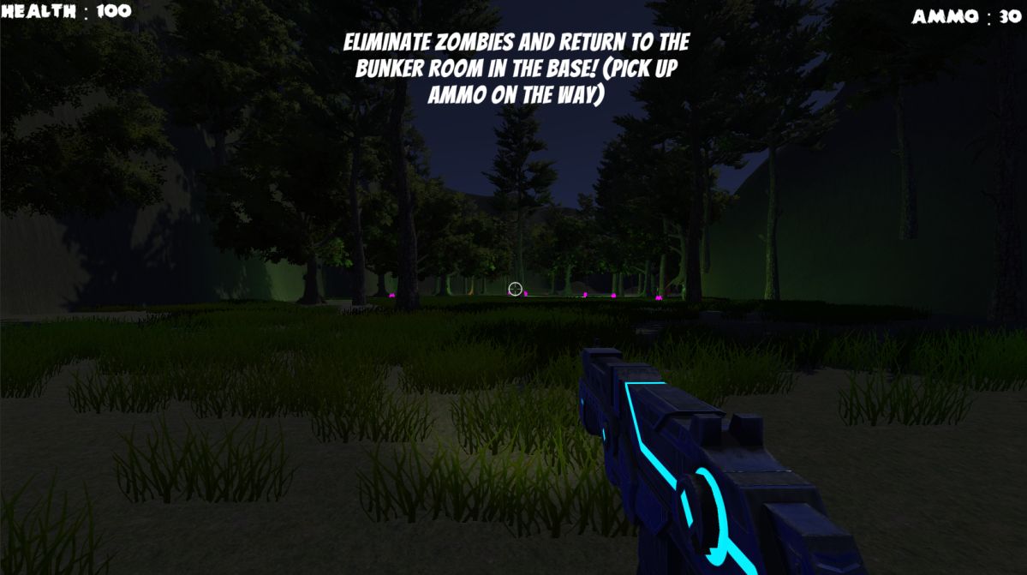
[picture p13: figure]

The HFController class is used in the FPS game within a configuration script to map

game actions to the Hand Force Controller. Implementing the HFController this way allows for

the programmer to abstract the HFController logic from the rest of the game. For example, in the

HFConfig script the “moveForward” action may be mapped to sensor 2, and therefore, another

script that contains the logic to move forward only has to reference the HFConfig.moveForward

field and not the actual sensor ID. Controller calibration is implemented in the FPS demo such

that the calibration values are retrieved from the Unity PlayerPrefs object and are used as a

resting threshold for the sensors.

(Kveton)

Figure 7: First-Person Shooter Game Use-Case Diagram

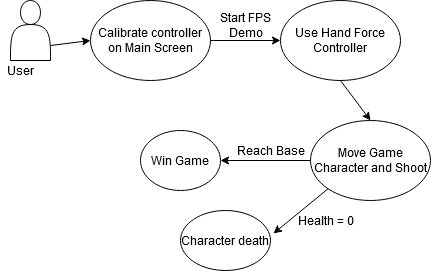
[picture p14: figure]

Testing Results

The serial communication subsystem is the most tested subsystem in the project because

every other subsystem is dependent on the communication functioning properly. The testing of

this subsystem was performed using a unit testing approach to verify functionality of the various

components within the subsystem. As each component of the subsystem was implemented it was

tested to meet the necessary functionality in various use cases. This approach allowed for the

subsystem to be implemented in a modular way such that refactoring code would have a lower

probability of introducing complicated bugs.

Once the basic functionality of the serial communication subsystem was implemented,

the subsystem was tested against various use cases to determine what exceptions should be

handled to avoid software failure and what programming logic would need to be redesigned.

Early testing and refactoring allowed for this subsystem to be integrated with other subsystems

more efficiently.

(Kveton)

Table 1: Serial Communication Testing Outline

Use cases and scenarios | Results
Sensor data packets being transferred. | Possibility of raising IndexOutOfRange exception when parsing message in C#. Solution involved clearing the input buffer in case of leftover data.
Serial port name is hardcoded and then a different machine/operating system is used. | Port is not found based on the given name in code giving errors. Solution involved designing an algorithm to programmatically open the port.
Serial data being used to move Unity gameObjects. | Framerate when moving an object becomes very slow and choppy. Core issue is due to the SerialPort.ReadLine() function blocking until data is available to read. Solution involved checking for data before calling the function.
Port finding algorithm is implemented, but without proper port closing logic. | Testing this led to the knowledge that there are two cases in which a port will not connect: 1. A response message was received over the port, but it is incorrect. 2. No response received.
The user quickly stops and starts the Unity application. | The port will not reconnect. This was due to the Arduino code already receiving the “wakeup”. Solution involved implementing a timeout mechanism in the Arduino to return to “sleep” after a period of disconnection.
The user disconnects and reconnects the controller during Unity application runtime. | IOException thrown causing crash. Solution involved implementing an IsConnected variable and a ReconnectDevice() function in

| HFController.
Game logic is programmed to use the HFController.GetSensorValue() function when the port is not open. | IOException thrown causing crash. Solution involved wrapping HFController code logic in an if statement using HFController.IsConnected.

Discussion on Lessons Learned

Lillian Boettcher:

During this project I learned a great deal about hardware to software connections. As a

programmer I had little hardware experience in terms of consolidating hardware and ensuring it

works as effectively as a software. And while I had used Unity before to develop, it is my first

time doing it as a team, which will probably serve me well in future programming projects

throughout my career that rely heavily on collaboration.

Grant Kveton:

Working on the Hand Force Controller project has given me a good experience of

designing, implementing, and testing a software application from start to finish. Before the

Engineering Design course, I had some basic experience and interest in using the Unity game

engine. During the research and design stages of the project, I learned a lot about the Arduino

documentation, C# documentation, and standards for the Unity game engine. I had an interest in

testing practices and wanted to integrate that into the components of the project I was working

on. Overall, I learned a lot about the importance of writing clean modular and testable code and the effects on debugging and development. I also gained experience in working with a team on a

large software project such as this. Given the state of affairs with COVID-19 I was exposed to

working with the team remotely and the importance of communication.

Dhaval Manojkumar Shirvi:

While working on this project, I learned a lot about Unity as it was my first time

developing in unity. While working on the keyboard emulator, I picked up on a lot of the unity’s

UI mechanics. I have used python before, however it was my first time working with ironpython.

Due to COVID-19 and me being in India, I learned a great deal about time management due to

different time zones, and the importance of communication as we were working on the project

remotely. It was a great experience to work on this project with my team.

### Conclusion

The project ended successfully, meeting all of the initial functional and nonfunctional

requirements set. The project design changed slightly throughout, but only a relatively small

amount and all changes made were to better follow the requirements and goals of the project.

Feedback on the project is fairly positive. The development team finds the Hand Force

Controller easy to use and other individuals found it also easy to use. One criticism by a

non-developer tester was that having a usable platform required having access to a 3D printer

when the goal of this project is to have the controller as accessible to the world as possible. One

way that this could be addressed is by including a DIY (do-it-yourself) instruction manual for

assembling a platform out of construction parts, such as cardboard. This could also turn

assembly into a fun project and encourage developers and users alike to become more involved

in the hardware assembly even if they do not put the hardware together themselves.

Additionally, the project could be improved with the use of standardizing components.

The jump wires used to go from the Arduino Uno to the breadboard circuits are very large and

bulky, making the hardware hard to consolidate with a platform. Additionally, finding force

sensors that can be responsive to fingers may be difficult for some users who wish to build the

Hand Force Controller. Therefore, people may benefit if the repository also includes a list of

recommended parts for the user to use, which would not just consist of the parts the developers

used but also a list of parts with minimal cost and maximum effectiveness for the purposes of the

controller.

(Boettcher)

### References

Bierre, Kevin, et al. “Game Not Over: Accessibility Issues in Video Games.” International

Game

Developers Association, 2005.

Cook, David, et al. “Virtual Reality and Older Hands: Dexterity and Accessibility in Hand-Held

VR Control.” Association for Computing Machinery, vol. 5, 2019, pp. 147-151.

“Force Sensitive Resistor (FSR).” Adafruit, 2020,

learn.adafruit.com/force-sensitive-resistor-fsr/overview.

Glinert, Eitan. “The Human Controller: Usability and Accessibility in Video Game Interfaces.”

Massachusetts Institute of Technology, 2008.

“Hardware and Software Specifications.” Unreal Engine, Epic Games, 2020,

docs.unrealengine.com/en-US/GettingStarted/RecommendedSpecifications/index.html.

Iacopetti, Fabrizio, et al., “Game Console Controller Interface for People with Disability.”

International Conference on Complex, Intelligent and Software Intensive Systems, 2008,

pp. 757-762.

“Keyboard 0.13.5.” Python, Python Software Foundation, 2020, pypi.org/project/keyboard.

Kry, Paul, et al., “HandNavigator: Hands-on Interaction for Desktop Virtual Reality.” Virtual

Reality Software And Technology, vol. 8, 2008, pp. 53-60.

“Language Reference.” Arduino, 2020, www.arduino.cc/reference/en.

Liechti, Chris. “pySerial API.” pySerial, 2017,

pyserial.readthedocs.io/en/latest/pyserial_api.html.

Maggiorini, Dario, et al., “Evolution of Game Controllers: Toward the Support of Gamers with

Physical Disabilities.” Computer-Human Interaction Research and Applications,

Springer Nature, 2019, pp. 66-89.

“SerialPort Class.” Microsoft, 2020,

docs.microsoft.com/en-us/dotnet/api/system.io.ports.serialport.

Tristem, Ben, and Rick Davidson. “Complete C# Unity Game Developer 3D.” Udemy, 2020,

www.udemy.com/course/unitycourse2.

“74HC4051 Product Data Sheet.” NXP Semiconductors, 2016,

cdn.sparkfun.com/assets/learn_tutorials/5/5/3/74HC_HCT4051.pdf.

### Organization Chart

Figure 8: Organization Chart

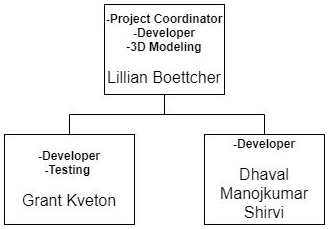
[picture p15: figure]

### Budget

The Hand Force Controller is a cost-effective project due to its use of minimal hardware

components and free-to-use computer software. The original part list only included five force

sensors and did not include a multiplexer. During the implementation stage, the constraint of

only having six analog inputs on the Arduino microcontroller was handled by introducing a

multiplexer to include more sensors in the system. The main software programs used in

development, such as Unity and the Arduino IDE, are free-to-use in the context of educational

projects.

Due to the current state of affairs with COVID-19, the team was not able to work on the

project together on campus. Extra parts were ordered so that each team member could work on

their own individual hardware setup. It was important for the team members to have identical

parts and configurations to reduce the potential for error. Table # below shows the component

and total cost for a single Hand Force Controller hardware setup.

(Kveton)

Table 2: Project Budget

Part Number | Description | Quantity | Unit Price | Total Cost
ARDUINO UNO R3 | Arduino Uno Microcontroller Board | 1 | $22.00 | $22.00
FSR400 | Force Sensitive Resistor | 8 | $6.60 | $52.80
74HC4051 | Multiplexer Breakout | 1 | $5.95 | $5.95

- | - | - | - | $80.75

### Appendices

Hardware Schematics

Figure 9: Circuit Diagram

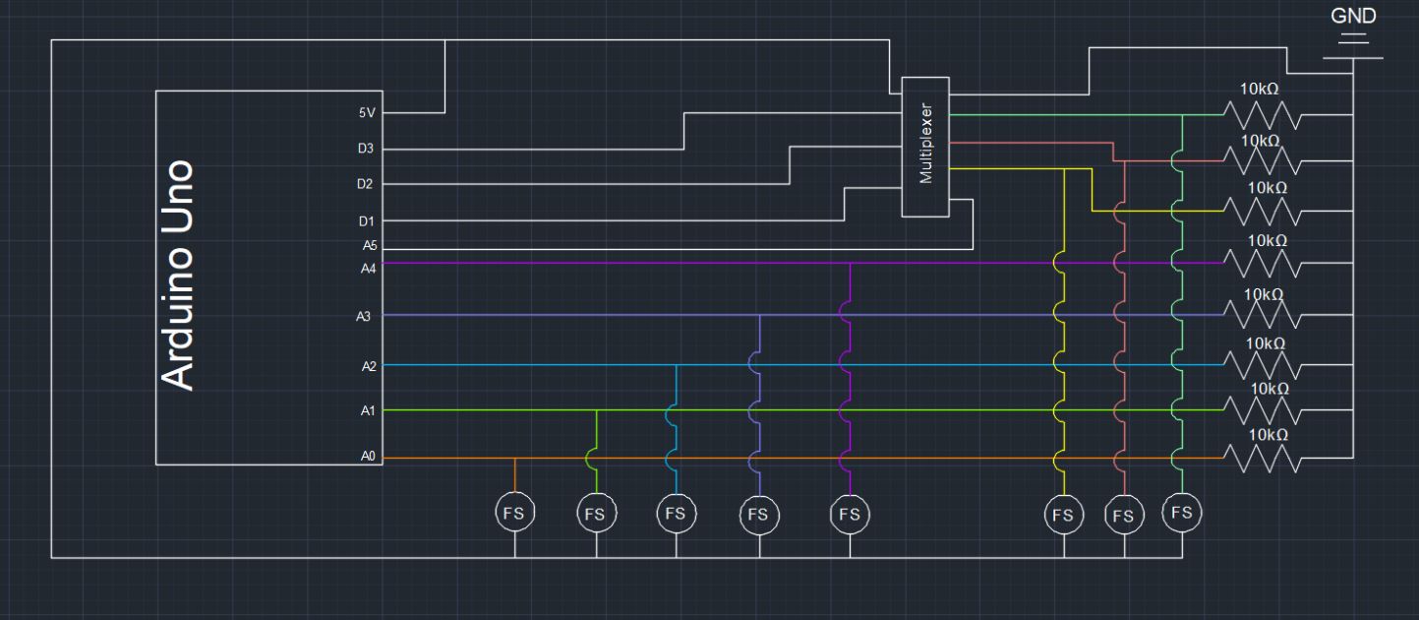
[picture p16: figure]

Program Schematics

Figure 10: Serial Communication Pseudocode Schematic

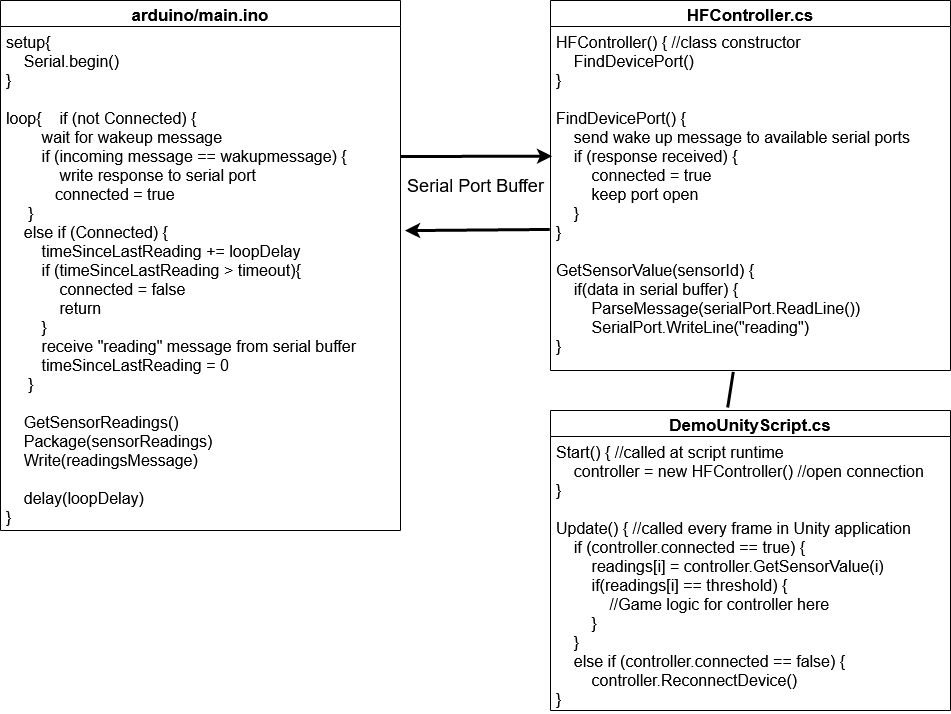
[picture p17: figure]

Figure 11: Application Main Screen UI Design

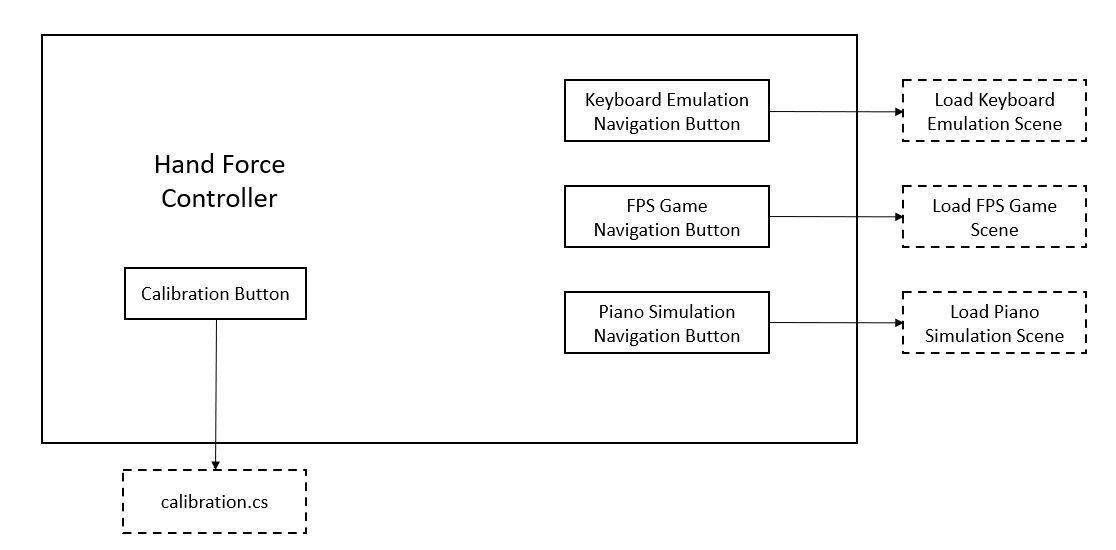
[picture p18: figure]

Figure 12: Calibration Activity Diagram

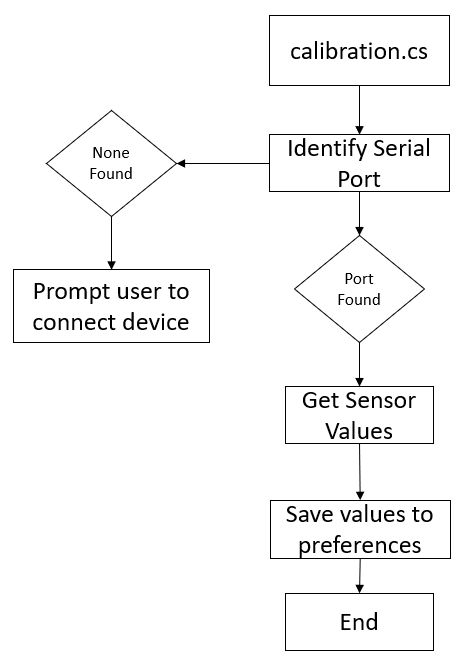
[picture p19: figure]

Figure 13: Keyboard Emulation Activity Diagram

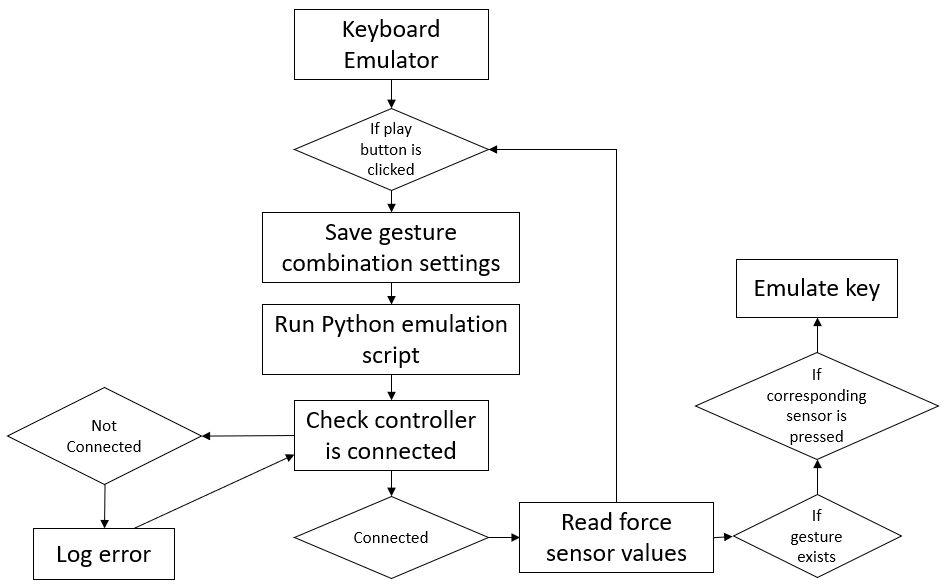
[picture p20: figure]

Figure 14: Piano Simulation Activity Diagram

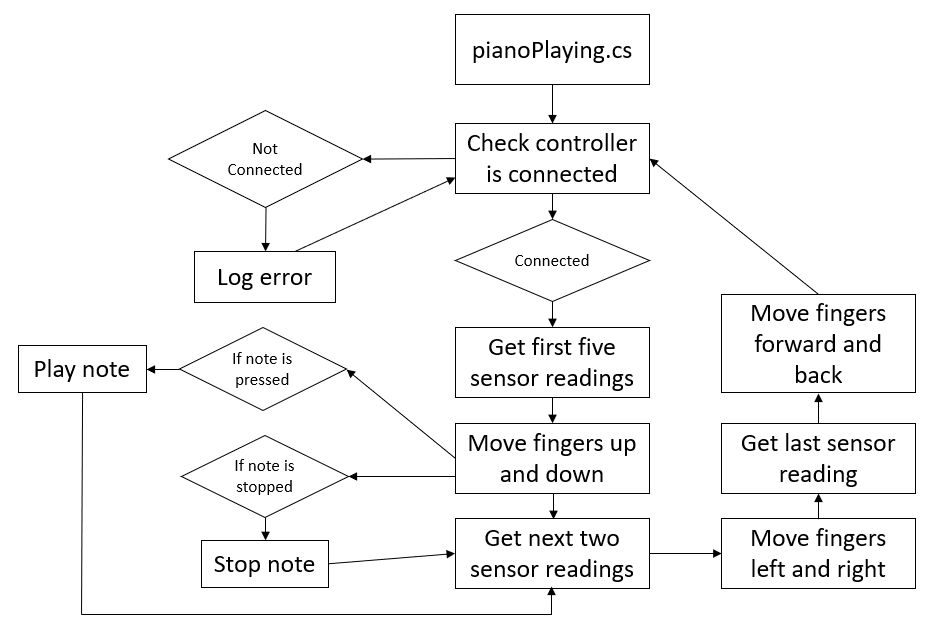
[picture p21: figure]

Figure 15: First-Person Shooter Game Activity Diagram

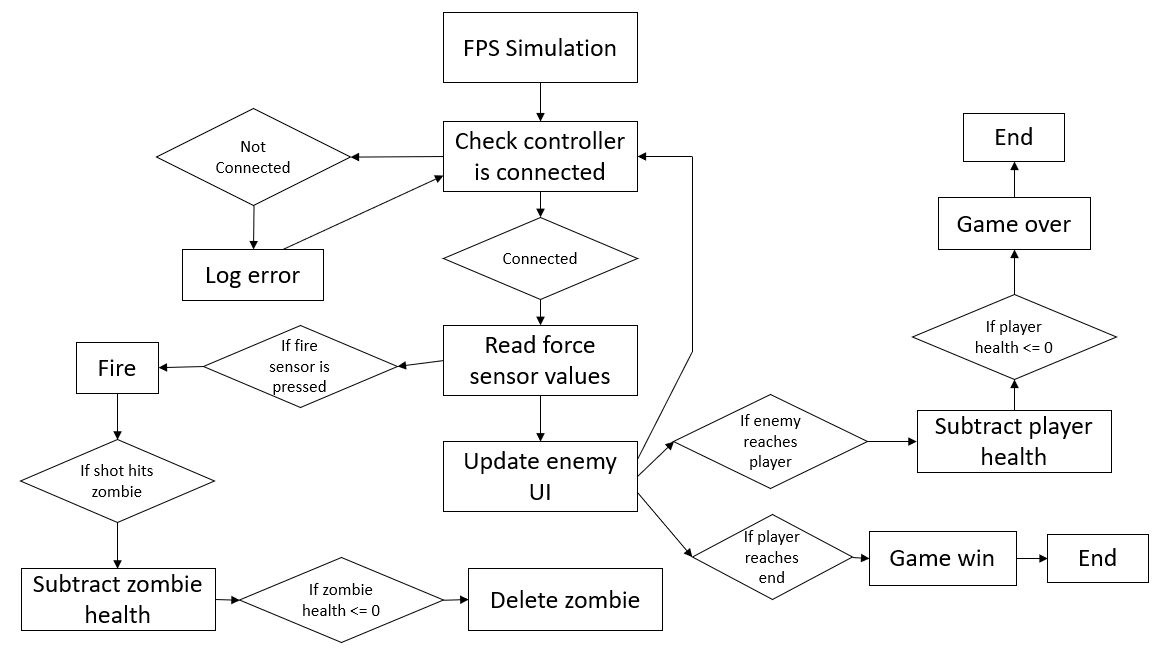
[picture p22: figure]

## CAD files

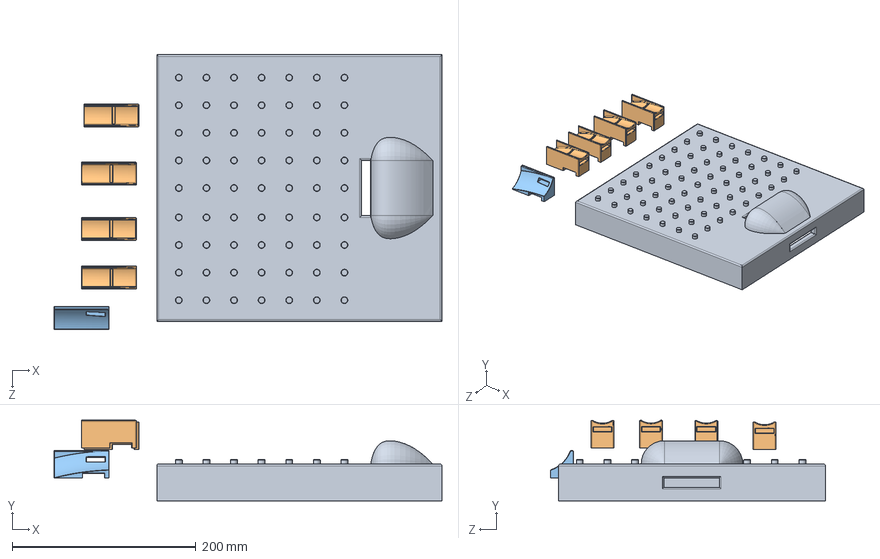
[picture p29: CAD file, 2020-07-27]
hfc 3d model/hfs assembly.SLDASM
421.7 x 87.5 x 298.6 mm
hfc part1 base
hfc Part2 fingers x 4
hfc Part3 thumb

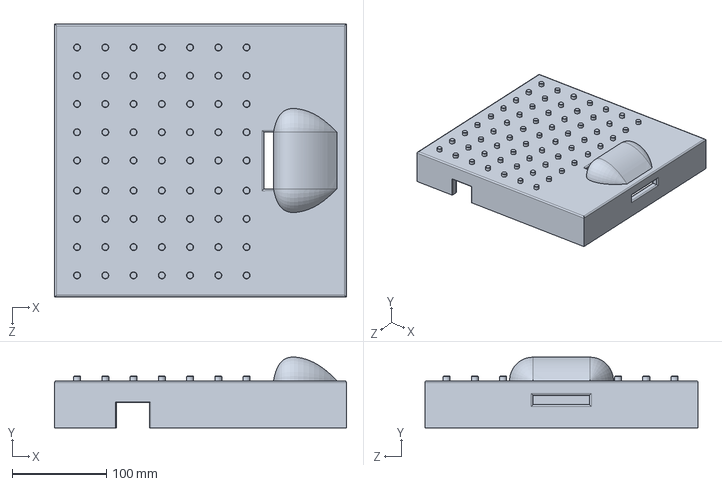
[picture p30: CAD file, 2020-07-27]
hfc 3d model/hfc part1 base.SLDPRT
310.0 x 75.2 x 290.0 mm

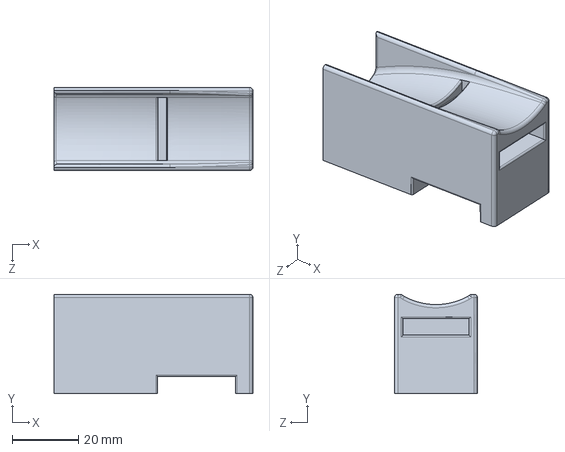
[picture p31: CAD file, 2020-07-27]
hfc 3d model/hfc Part2 fingers.SLDPRT
60.0 x 30.0 x 25.0 mm

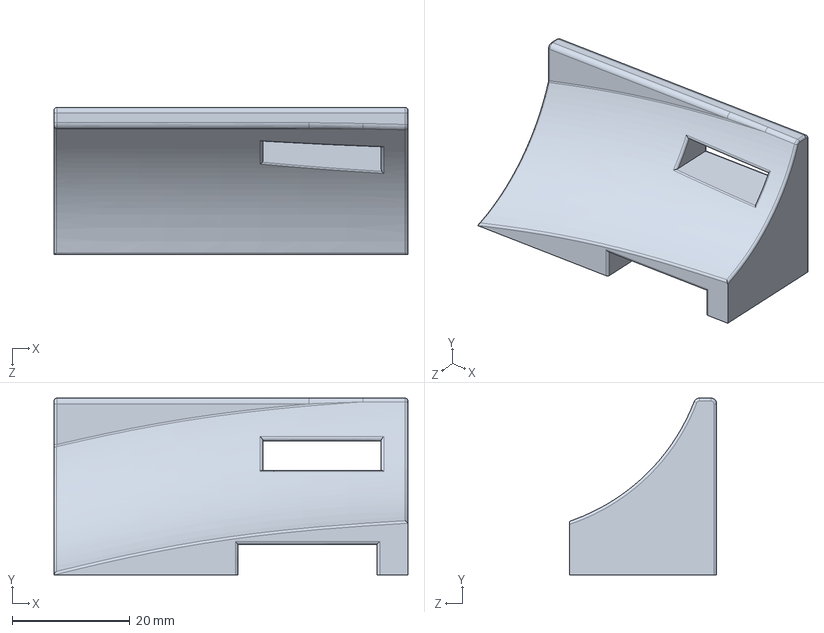
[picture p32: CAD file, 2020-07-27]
hfc 3d model/hfc Part3 thumb.SLDPRT
60.0 x 30.0 x 25.0 mm

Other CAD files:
hfc 3d model/stl files/hfc Part2 fingers.STL
hfc 3d model/stl files/hfc Part3 thumb.STL
hfc 3d model/stl files/hfc part1 base.STL

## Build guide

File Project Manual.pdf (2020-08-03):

## Hand Force Controller User Manual

Lillian Boettcher

Grant Kveton

Dhaval Manojkumar Shirvi

Contents

Getting Started --------------------------------------- 2

Manual Hardware Assembly ---------------------- 2

Manual Platform Assembly ------------------------ 3

Arduino Script Functionality ----------------------- 4

Main Software Application ------------------------ 5

Calibration --------------------------------------------- 6

Piano Simulation ------------------------------------- 6

FPS Simulation ---------------------------------------- 8

Keyboard Emulation --------------------------------- 10

Getting Started

The hand force controller and software consists of:

- A 3D printable platform
- Eight force sensors
- Multiplexer chip (such as 74HC4051 breadboard chip)
- Wires, wire jumpers, and/or other conductive connectors
- Arduino Uno
- USB cable
- Arduino code script
- Hand Force Controller Application

If you are manually assembling the hardware components and platform, the instructions are as

follows:

Manual Hardware Assembly

The force sensors need to be connected to the Arduino Uno by the use of wires, so a

breadboard or other wire platform is required. The connections require having the first five

force sensors connected to the first five analog ports on the Arduino. The remaining three

force sensors should go through the multiplexer. The multiplexer connections are specific to

whatever chip is used, as the type of chip used will define how the sensors will be connected.

Manual Platform Assembly

The components of the platform can be found in the repository as three separate files, a

“finger” model, a “thumb” model, and a “base” model. To have a complete platform, the base

and thumb are printed once while the finger model is printed four times.

The base consists of round pegs, which the thumb and finger models can fit into after

they are printed. The wires to the sensors can be put through slits found in each of the fingers,

including the thumb, or underneath, depending on what allows them to connect with where

the Arduino is placed.

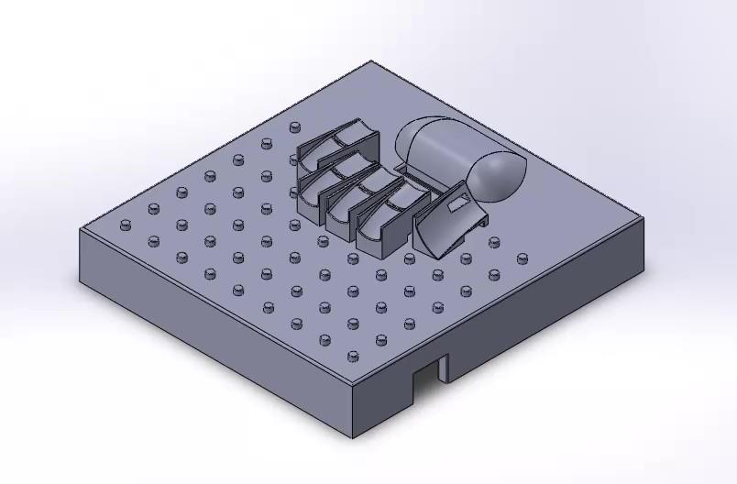
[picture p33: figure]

Arduino Script Functionality

The Arduino can be connected using a USB cable or a Bluetooth dangle. The script to be

run on the Arduino Uno, main.ino, can be downloaded from the Github Repository in the

Arduino folder. The Arduino software can be downloaded from

www.arduino.cc/en/Main/Software.

When the software is downloaded and installed for the correct operating system, open

the software. In the File tab on the top right, and select Open. Then navigate to the

downloaded script. When the script is open and the Arduino is connected to the computer

(and recognized by the computer), click the Upload arrow at the top left. This will load the

script onto the Arduino. If the Serial Monitor button on the top right of the software is clicked,

a serial port reader will open. If the Arduino script is running and the force sensors are

connected properly, the readings from each force sensor should appear on the port in live time.

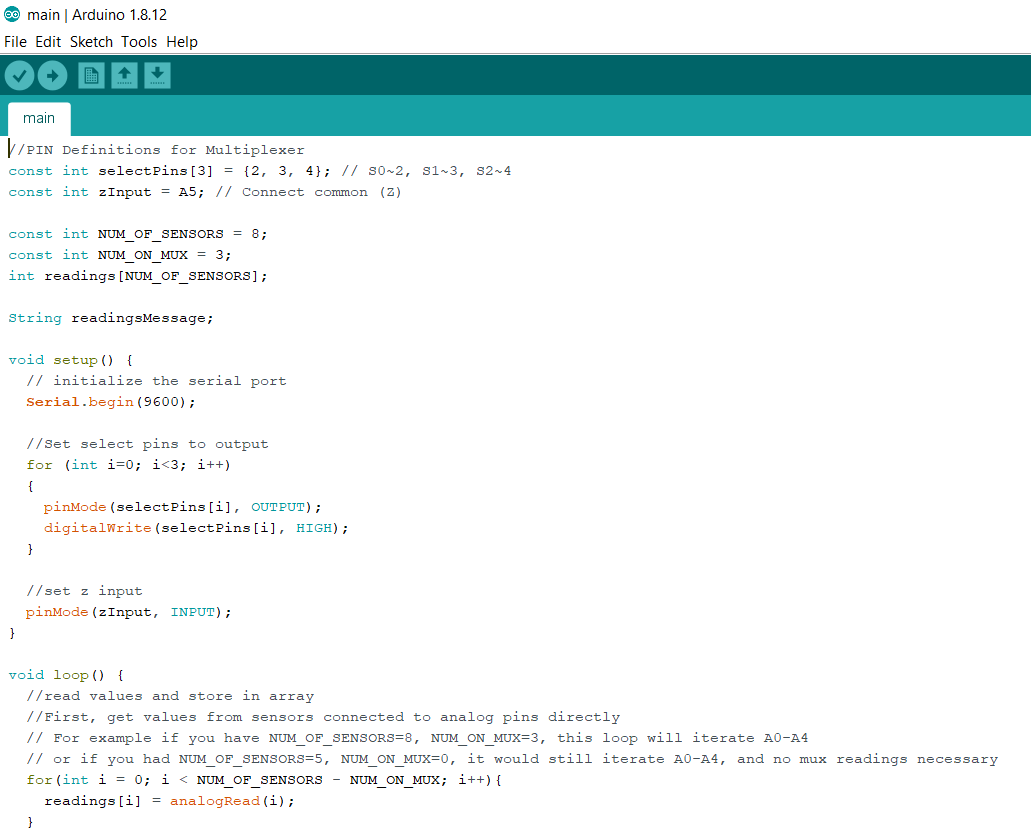
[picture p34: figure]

Main Software Application

The Hand Force Controller Application can be downloaded from the Github repository.

When it is downloaded into a folder, it will contain an executable and the application assets.

There are two ways to access the functionality: opening the executable (the simplest method)

or by opening the scene assets (for developers).

The scenes, which can be individually by developers, can be opened if Unity 3D is

downloaded by the user. Then the source code and assets in the program can be viewed,

exactly as they were released as an executable.

When accessing the application through the executable, a main screen will be displayed

with calibration and buttons for accessing different parts of the application.

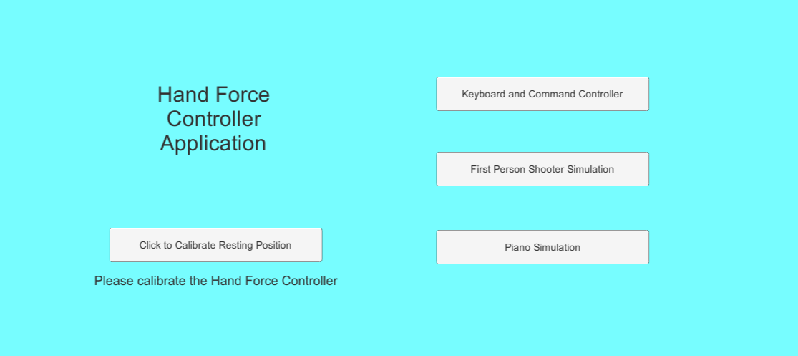
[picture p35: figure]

Calibration

The Hand Force Controller can be easily calibrated on the main screen of the software

application. There is a single button for the calibration, underneath the title text. Calibrating

can be done by having the hand that will be used rest on the Hand Force Controller and then

using the other hand, while the controller hand is resting on the controller, to click the

calibration button.

For the calibration button to work, please make sure that the controller is plugged in. If

the controller is not plugged in, an error message will display prompting the user to plug in the

controller to the computer. Additionally, the Arduino script needs to be running on the

Arduino, else the software will not be able to receive information from the Arduino to sense

the force sensor values being created by the user.

When the calibration process is complete, the response text underneath the button

should display “Calibrated!” The calibration should save when testing on one of the

simulations. If in the simulation the force sensors do not respond as desired, as in they are too

sensitive or not sensitive enough, this can be fixed by recalibrating the sensors through the

same process.

Piano Simulation

The piano simulation is opened as a Unity scene via the main software application’s

main page. The simulation displays a piano from a top orthogonal view along with five color-coded fingers. The red finger corresponds to the left-most sensor and the blue finger

corresponds to the fifth sensor, which will be the thumb and pinky finger or vice versa

depending on whether or not the user is using their left hand or right hand. The next two

sensors, which are default to be placed underneath the sides of the palm of the selected hand,

indicate left or right movement. When the sixth sensor is pressed, all five fingers move left.

When the seventh sensor is pressed, all five fingers move right. The eight sensor is default

considered to be placed at the back of the hand with some strap or board keeping it pressed

against the back of the hand. Upon putting pressure on it through raising the back of the hand,

the five fingers on the piano move forward. Upon release of pressure, the fingers move back

before the black keys and onto only white keys.

Each key press corresponds to an audio output of the corresponding key. When the

hand is not moved left, right, or forward, the default notes that can be sounded are C4, D4, E4,

F4, and G4. This is because the left-most finger starts by default on middle C, or C4. If the hand

does not start on C4, then you may need to check your hardware or recalibrate the sensors so

the hand does not move without user intent.

To visually see what notes are being pressed, when a note plays it changes its color.

When a note stops playing, it reverts to its original color. Black keys when played are set to

change from black to purple when played and white keys are set to change from white to pink

when played. A note changing color should correspond to note audio being played. If no notes

are heard when keys are pressed, then you may need to check that your audio is turned on for

the software application.

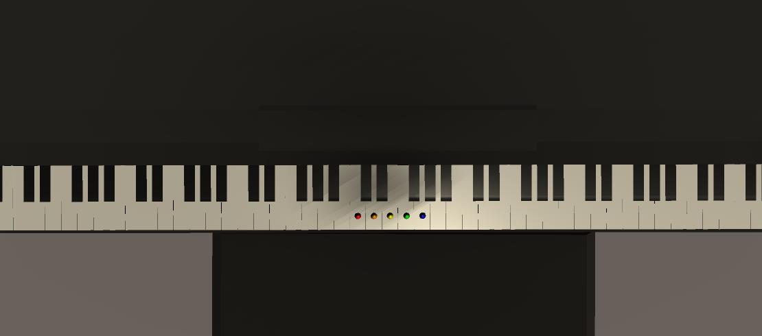
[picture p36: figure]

FPS Simulation

A first-person shooter (FPS) consists of the user taking a virtual weapon, pointing, and

shooting that weapon at objects or enemies in a first-person view. This part of the application

demonstrates the Hand Force Controller’s ability to be used for playing FPS games and to be

used when developing games, as this FPS was developed.

The goal of the game is to get to the end with the user’s gun weapon. During the game,

zombies will attempt to approach and damage the player. The user can attack these zombies to

defeat them by shooting them with ammo. The ammo is collected as glowing objects along the

way. The user wins if they can get to the end without losing all of their health.

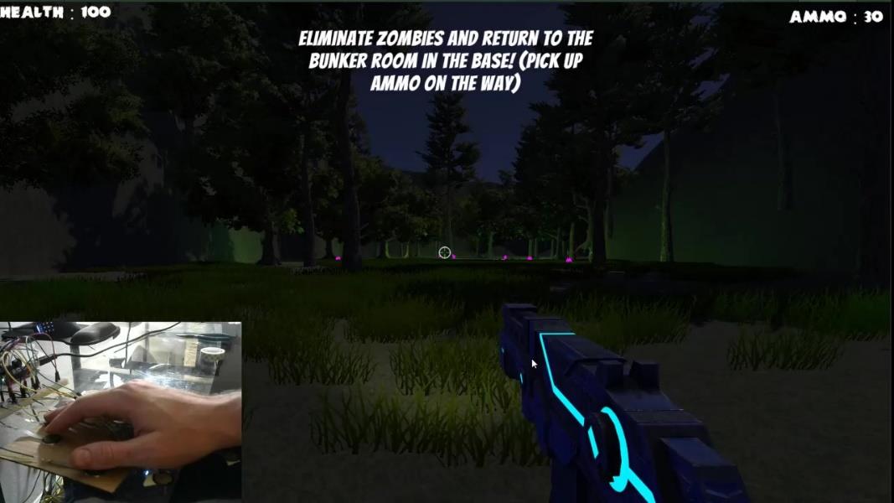
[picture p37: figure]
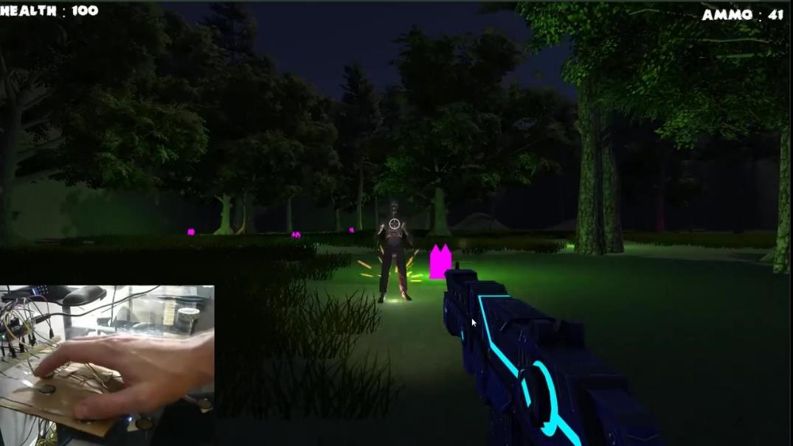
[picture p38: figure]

The controls to play are as follows by default (referring to sensors as 0-7):

- Move forward: 2
- Move backward: 6
- Move left: 1
- Move right: 3
- Rotate left: 5
- Rotate right: 7

- Jump: 4
- Fire: 0

The controls can be altered by accessing the scene in Unity by programmers and

developers. There is an “HF Config” script that can be viewed in the Unity editor. The values

are set to the above controls by default, but they can change by changing the values set in the

HF Config variables, where they can be set to values from 0 to 7 for sensors 1 through 8.

Keyboard Emulation

The Hand Force Controller can be used to emulate computer commands to control

games and different computer software. This is done by choosing which gestures, or which

sensor inputs, correspond to which keyboard or computer mouse commands. After any desired

gesture commands are set, the controls can go into effect by pressing “Play.”

What this does is opens an executable Python file, which runs how the sensors should

be used based on the commands set on the computer emulation screen. This means that when

the user performs a gesture on the Hand Force Controller that is set to activate a computer

commands, such as press a keyboard key, the command will take effect. This allows the Hand

Force Controller to be used to play computer games and control other computer and software

actions. For example, say a game the user wants to play has the attack button set to the

spacebar on the computer keyboard. If the user, on the keyboard emulation settings, set the

first force sensor to activate the spacebar, then the user can press the first force sensor to

attack in the game.

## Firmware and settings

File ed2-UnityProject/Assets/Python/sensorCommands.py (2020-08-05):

import keyboard
import serial
from time import sleep
from GetCommand import GetCommands

gc = GetCommands()#reads file
commands = gc.getCommands()#gets commands from the file
threshold = 800

NUMBER_OF_SENSORS = 8
readings = [0] * 8
portName = gc.getPortName()

isConnected = False
serialPort = serial.Serial(portName, timeout=1)
serialPort.flush()


# TODO iterate through available ports and find correct one programmatically
def wakeUpController():
    global isConnected
    serialPort.write("WakeUp\n".encode())  # send wake up message
    response = serialPort.readline().decode().strip()
    print(response)
    if (response == "ArduinoUno"):
        print('response == "ArduinoUno" TRUE')
        isConnected = True

def getSensorValue(sensorId):
    readFromSerial()
    return readings[sensorId]

def readFromSerial():
    serialMessage = serialPort.readline().decode().strip()
    serialPort.write("reading\n".encode())

    if (len(serialMessage) != 0):
        parseMessage(serialMessage)

def parseMessage(serialMessage):
    global readings
    j = 0

    for i in range(NUMBER_OF_SENSORS):
        messageValue = ""

        while serialMessage[j] != ',':
            messageValue += serialMessage[j]
            j = j+1
        readings[i] = int(messageValue)
        j = j+1



def pressKey(i, combo):
    if(commands[combo] != ""):
        keyboard.press(commands[combo]) #will keep repeating until released
        print("pressing " + commands[combo])
            
    else:    
        keyboard.press(commands[i]) #will keep repeating until released
        print("pressing " + commands[i])

        
while True:
    if(isConnected):
        #finger 1
        if(getSensorValue(0) > threshold):
            if(getSensorValue(1) > threshold):
                if(getSensorValue(2) > threshold):
                    if(getSensorValue(3) > threshold):
                        if(getSensorValue(4) > threshold):
                            #finger1,2,3,4,5
                            pressKey(0, 30)
                        elif(commands[30] != "" and keyboard.is_pressed(commands[30])):
                            keyboard.release(commands[30])
                        #finger1,2,3,4
                        pressKey(0, 25)
                    elif(commands[25] != "" and keyboard.is_pressed(commands[25])):
                         keyboard.release(commands[25])
                    #finger 1,2,3,5
                    elif(getSensorValue(4) > threshold):
                        pressKey(0, 27)
                    elif(commands[27] != "" and keyboard.is_pressed(commands[27])):
                        keyboard.release[27]
                    #finger1,2,3 
                    pressKey(0,15)
                elif(commands[15] != "" and keyboard.is_pressed(commands[15])):
                    keyboard.release(commands[15])
                elif(getSensorValue(3) > threshold):
                    if(getSensorValue(4) > threshold):
                        #finger 1,2,4,5
                        pressKey(0, 28)
                    elif(commands[28] != "" and keyboard.is_pressed(commands[28])):
                        keyboard.release(commands[28])
                    #finger 1,2,4 
                    pressKey(0,18)
                elif(commands[18] != "" and keyboard.is_pressed(commands[18])):
                    keyboard.release(commands[18])        
                elif(getSensorValue(4) > threshold):
                    #finger 1,2,5
                    pressKey(0,20)
                elif(commands[20] != "" and keyboard.is_pressed(commands[20])):
                    keyboard.release(commands[20])
                #finger 1,2
                pressKey(0, 5)
            elif(commands[5] != "" and keyboard.is_pressed(commands[5])):
                keyboard.release(commands[5])    
                        
            elif(getSensorValue(2) > threshold):
                if(getSensorValue(3) > threshold):
                    if(getSensorValue(4) > threshold):
                        #finger1,3,4,5
                        pressKey(0,29)
                    elif(commands[29] != "" and keyboard.is_pressed(commands[29])):
                        keyboard.release(commands[29])
                    #finger1,3,4
                    pressKey(0, 21)
                elif(commands[21] != "" and keyboard.is_pressed(commands[21])):
                    keyboard.release(commands[21])    
                #finger 1,3,5  
                elif(getSensorValue(4) < threshold):
                    pressKey(0, 23)
                elif(commands[23] != "" and keyboard.is_pressed(commands[23])):
                    keyboard.release(commands[23])    
                #finger1,3
                pressKey(0, 9)
            elif(commands[9] != "" and keyboard.is_pressed(commands[9])):
                keyboard.release(commands[9])

            elif(getSensorValue(3) > threshold):
                if(getSensorValue(4) > threshold):
                    #finger1,4,5
                    pressKey(0,24)
                elif(commands[24] != "" and keyboard.is_pressed(commands[24])):
                    keyboard.release(commands[24])    
                #finger1,4
                pressKey(0, 12)
            elif(commands[12] != "" and keyboard.is_pressed(commands[12])):
                    keyboard.release(commands[12])

            elif(getSensorValue(4) > threshold):
                #finger1,5
                pressKey(0, 14)
            elif(commands[14] != "" and keyboard.is_pressed(commands[14])):
                keyboard.release(commands[14])

            #finger 1    done
            else:
                pressKey(0,0)
        else:
            keyboard.release(commands[0])
            
        #finger 2
        if(getSensorValue(1) > threshold):
            if(getSensorValue(0) > threshold):
                if(getSensorValue(2) > threshold):
                    if(getSensorValue(3) > threshold):
                        if(getSensorValue(4) > threshold):
                            #finger2,1,3,4,5
                            pressKey(1, 30)
                        elif(commands[30] != "" and keyboard.is_pressed(commands[30])):
                            keyboard.release(commands[30])    
                        #finger2,1,3,4
                        pressKey(1, 25)
                    elif(commands[25] != "" and keyboard.is_pressed(commands[25])):
                        keyboard.release(commands[25])    
                    #finger 2,1,3,5
                    elif(getSensorValue(4) > threshold):
                        pressKey(1, 27)
                    elif(commands[27] != "" and keyboard.is_pressed(commands[27])):
                        keyboard.release(commands[27])    
                    #finger2,1,3 
                    pressKey(1,15)
                elif(commands[15] != "" and keyboard.is_pressed(commands[15])):
                    keyboard.release(commands[15])
                    
                elif(getSensorValue(3) > threshold):
                    if(getSensorValue(4) > threshold):
                        #finger 2,1,4,5
                        pressKey(1, 28)
                    elif(commands[28] != "" and keyboard.is_pressed(commands[28])):
                        keyboard.release(commands[28])
                    #finger 2,1,4 
                    pressKey(1,18)
                elif(commands[18] != "" and keyboard.is_pressed(commands[18])):
                    keyboard.release(commands[18])
                    
                elif(getSensorValue(4) > threshold):
                    #finger 2,1,5
                    pressKey(1,20)
                elif(commands[20] != "" and keyboard.is_pressed(commands[20])):
                    keyboard.release(commands[20])
                #finger 2,1
                pressKey(1, 5)
            elif(commands[5] != "" and keyboard.is_pressed(commands[5])):
                    keyboard.release(commands[5])    
                        
            elif(getSensorValue(2) > threshold):
                if(getSensorValue(3) > threshold):
                    if(getSensorValue(4) > threshold):
                        #finger2,3,4,5
                        pressKey(1,26)
                    elif(commands[26] != "" and keyboard.is_pressed(commands[26])):
                        keyboard.release(commands[26])
                    #finger2,3,4
                    pressKey(1, 16)
                elif(commands[16] != "" and keyboard.is_pressed(commands[16])):
                    keyboard.release(commands[16])    
                #finger 2,3,5  
                elif(getSensorValue(4) < threshold):
                    pressKey(1,19)
                elif(commands[19] != "" and keyboard.is_pressed(commands[19])):
                    keyboard.release(commands[19])    
                #finger2,3
                pressKey(1, 6)
            elif(commands[6] != "" and keyboard.is_pressed(commands[6])):
                    keyboard.release(commands[6])

            elif(getSensorValue(3) > threshold):
                if(getSensorValue(4) > threshold):
                    #finger2,4,5
                    pressKey(1,22)
                elif(commands[22] != "" and keyboard.is_pressed(commands[22])):
                    keyboard.release(commands[22])    
                #finger2,4
                pressKey(1, 10)
            elif(commands[10] != "" and keyboard.is_pressed(commands[10])):
                keyboard.release(commands[10])

            elif(getSensorValue(4) > threshold):
                #finger2,5
                pressKey(1, 13)
            elif(commands[13] != "" and keyboard.is_pressed(commands[13])):
                keyboard.release(commands[13])

            #finger 2    done
            else:
                pressKey(1,1)

        else:
            keyboard.release(commands[1])
        #finger 2 done
        
                               
        #finger3  
        if(getSensorValue(2) > threshold):
            if(getSensorValue(1) > threshold):
                if(getSensorValue(0) > threshold):
                    if(getSensorValue(3) > threshold):
                        if(getSensorValue(4) > threshold):
                            #finger3,1,2,4,5
                            pressKey(2, 30)
                        elif(commands[30] != "" and keyboard.is_pressed(commands[30])):
                            keyboard.release(commands[30])   
                        #finger3,1,2,4
                        pressKey(3, 25)
                    elif(commands[25] != "" and keyboard.is_pressed(commands[25])):
                        keyboard.release(commands[25])    
                    #finger 3,1,2,5
                    elif(getSensorValue(4) > threshold):
                        pressKey(2, 27)
                    elif(commands[27] != "" and keyboard.is_pressed(commands[27])):
                        keyboard.release(commands[27])    
                    #finger3,1,2 
                    pressKey(2,15)
                elif(commands[15] != "" and keyboard.is_pressed(commands[15])):
                    keyboard.release(commands[15])        
                elif(getSensorValue(3) > threshold):
                    if(getSensorValue(4) > threshold):
                        #finger 3,2,4,5
                        pressKey(2, 26)
                    elif(commands[26] != "" and keyboard.is_pressed(commands[26])):
                        keyboard.release(commands[26])
                    #finger 3,2,4 
                    pressKey(2,16)
                elif(commands[16] != "" and keyboard.is_pressed(commands[16])):
                    keyboard.release(commands[16])        
                elif(getSensorValue(4) > threshold):
                    #finger 3,2,5
                    pressKey(2, 19)
                elif(commands[19] != "" and keyboard.is_pressed(commands[19])):
                    keyboard.release(commands[19])
                #finger 3,2
                pressKey(2, 6)
                
            elif(commands[6] != "" and keyboard.is_pressed(commands[6])):
                    keyboard.release(commands[6])            
            elif(getSensorValue(0) > threshold):
                if(getSensorValue(3) > threshold):
                    if(getSensorValue(4) > threshold):
                        #finger1,3,4,5
                        pressKey(2,29)
                    elif(commands[29] != "" and keyboard.is_pressed(commands[29])):
                        keyboard.release(commands[29])
                    #finger1,3,4
                    pressKey(2, 21)
                elif(commands[21] != "" and keyboard.is_pressed(commands[21])):
                    keyboard.release(commands[21])   
                #finger 1,3,5  
                elif(getSensorValue(4) < threshold):
                    pressKey(2, 23)
                elif(commands[23] != "" and keyboard.is_pressed(commands[23])):
                    keyboard.release(commands[23])    
                #finger1,3
                pressKey(2, 9)
            elif(commands[9] != "" and keyboard.is_pressed(commands[9])):
                keyboard.release(commands[9])

            elif(getSensorValue(3) > threshold):
                if(getSensorValue(4) > threshold):
                    #finger3,4,5
                    pressKey(2,17)
                elif(commands[17] != "" and keyboard.is_pressed(commands[17])):
                    keyboard.release(commands[17])   
                #finger3,4
                pressKey(2,7)
            elif(commands[7] != "" and keyboard.is_pressed(commands[7])):
                keyboard.release(commands[7])

            elif(getSensorValue(4) > threshold):
                #finger3,5
                pressKey(2, 11)
            elif(commands[11] != "" and keyboard.is_pressed(commands[11])):
                keyboard.release(commands[11])

            #finger 3    done
            else:
                pressKey(2,2)
        else:
            keyboard.release(commands[2])

            
        #finger4
        if(getSensorValue(3) > threshold):
            if(getSensorValue(1) > threshold):
                if(getSensorValue(2) > threshold):
                    if(getSensorValue(0) > threshold):
                        if(getSensorValue(4) > threshold):
                            #finger1,2,3,4,5
                            pressKey(3, 30)
                        elif(commands[30] != "" and keyboard.is_pressed(commands[30])):
                            keyboard.release(commands[30])    
                        #finger1,2,3,4
                        pressKey(3, 25)
                    elif(commands[25] != "" and keyboard.is_pressed(commands[25])):
                        keyboard.release(commands[25])    
                    #finger 4,2,3,5
                    elif(getSensorValue(4) > threshold):
                        pressKey(3, 26)
                    elif(commands[26] != "" and keyboard.is_pressed(commands[26])):
                        keyboard.release(commands[26])    
                    #finger4,2,3 
                    pressKey(3,16)
                elif(commands[16] != "" and keyboard.is_pressed(commands[16])):
                    keyboard.release(commands[16])
                    
                elif(getSensorValue(0) > threshold):
                    if(getSensorValue(4) > threshold):
                        #finger 1,2,4,5
                        pressKey(3, 28)
                    elif(commands[28] != "" and keyboard.is_pressed(commands[28])):
                        keyboard.release(commands[28])
                    #finger 1,2,4 
                    pressKey(3,18)
                elif(commands[18] != "" and keyboard.is_pressed(commands[18])):
                    keyboard.release(commands[18])        
                elif(getSensorValue(4) > threshold):
                    #finger 4,2,5
                    pressKey(3,22)
                elif(commands[22] != "" and keyboard.is_pressed(commands[22])):
                    keyboard.release(commands[22])
                #finger 4,2
                pressKey(3, 10)
            elif(commands[10] != "" and keyboard.is_pressed(commands[10])):
                keyboard.release(commands[10])
                
                        
            elif(getSensorValue(2) > threshold):
                if(getSensorValue(0) > threshold):
                    if(getSensorValue(4) > threshold):
                        #finger1,3,4,5
                        pressKey(3,29)
                    elif(commands[29] != "" and keyboard.is_pressed(commands[29])):
                        keyboard.release(commands[29])
                    #finger1,3,4
                    pressKey(3, 21)
                elif(commands[21] != "" and keyboard.is_pressed(commands[21])):
                    keyboard.release(commands[21])
                    
                #finger 4,3,5  
                elif(getSensorValue(4) < threshold):
                    pressKey(3, 17)
                elif(commands[17] != "" and keyboard.is_pressed(commands[17])):
                    keyboard.release(commands[17])    
                #finger4,3
                pressKey(3, 7)
            elif(commands[7] != "" and keyboard.is_pressed(commands[7])):
                    keyboard.release(commands[7])


            elif(getSensorValue(0) > threshold):
                if(getSensorValue(4) > threshold):
                    #finger1,4,5
                    pressKey(3,24)
                elif(commands[24] != "" and keyboard.is_pressed(commands[24])):
                    keyboard.release(commands[24])
                    
                #finger1,4
                pressKey(3, 12)
            elif(commands[12] != "" and keyboard.is_pressed(commands[12])):
                keyboard.release(commands[12])

            elif(getSensorValue(4) > threshold):
                #finger4,5
                pressKey(3, 8)
            elif(commands[8] != "" and keyboard.is_pressed(commands[8])):
                keyboard.release(commands[8])

            #finger 4    done
            else:
                pressKey(3,3)
        else:
            keyboard.release(commands[3])

            
        #finger5
        if(getSensorValue(4) > threshold):
            if(getSensorValue(1) > threshold):
                if(getSensorValue(2) > threshold):
                    if(getSensorValue(3) > threshold):
                        if(getSensorValue(0) > threshold):
                            #finger1,2,3,4,5
                            pressKey(4, 30)
                        elif(commands[30] != "" and keyboard.is_pressed(commands[30])):
                            keyboard.release(commands[30])   
                        #finger5,2,3,4
                        pressKey(4,26)
                    elif(commands[26] != "" and keyboard.is_pressed(commands[26])):
                        keyboard.release(commands[26])    
                    #finger 1,2,3,5
                    elif(getSensorValue(0) > threshold):
                        pressKey(4, 27)
                    elif(commands[27] != "" and keyboard.is_pressed(commands[27])):
                        keyboard.release(commands[27])    
                    #finger5,2,3 
                    pressKey(4,19)
                elif(commands[19] != "" and keyboard.is_pressed(commands[19])):
                    keyboard.release(commands[19])        
                elif(getSensorValue(3) > threshold):
                    if(getSensorValue(0) > threshold):
                        #finger 1,2,4,5
                        pressKey(4, 28)
                    elif(commands[28] != "" and keyboard.is_pressed(commands[28])):
                        keyboard.release(commands[28])
                    #finger 5,2,4 
                    pressKey(4,22)
                elif(commands[22] != "" and keyboard.is_pressed(commands[22])):
                    keyboard.release(commands[22])        
                elif(getSensorValue(0) > threshold):
                    #finger 1,2,5
                    pressKey(4,20)
                elif(commands[20] != "" and keyboard.is_pressed(commands[20])):
                    keyboard.release(commands[20])
                #finger 5,2
                pressKey(4, 13)
            elif(commands[13] != "" and keyboard.is_pressed(commands[13])):
                    keyboard.release(commands[13])    
                        
            elif(getSensorValue(2) > threshold):
                if(getSensorValue(3) > threshold):
                    if(getSensorValue(0) > threshold):
                        #finger1,3,4,5
                        pressKey(4,29)
                    elif(commands[29] != "" and keyboard.is_pressed(commands[29])):
                        keyboard.release(commands[29])
                    #finger5,3,4
                    pressKey(4, 17)
                elif(commands[17] != "" and keyboard.is_pressed(commands[17])):
                    keyboard.release(commands[17])    
                #finger 1,3,5  
                elif(getSensorValue(0) < threshold):
                    pressKey(4, 23)
                elif(commands[23] != "" and keyboard.is_pressed(commands[23])):
                    keyboard.release(commands[23])    
                #finger5,3
                pressKey(4, 11)
            elif(commands[11] != "" and keyboard.is_pressed(commands[11])):
                    keyboard.release(commands[11])

            elif(getSensorValue(3) > threshold):
                if(getSensorValue(0) > threshold):
                    #finger1,4,5
                    pressKey(4,24)
                elif(commands[24] != "" and keyboard.is_pressed(commands[24])):
                    keyboard.release(commands[24])    
                #finger5,4
                pressKey(4, 8)
            elif(commands[8] != "" and keyboard.is_pressed(commands[8])):
                    keyboard.release(commands[8])

            elif(getSensorValue(0) > threshold):
                #finger1,5
                pressKey(4, 14)
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

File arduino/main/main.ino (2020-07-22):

int loopDelay = 50; //ms
String incomingMessage;
String wakeUpValue = "WakeUp";
String readingsMessage;
bool isConnected = false;
int timeSinceLastReading = 0; //time in ms since last reading
int connectionTimeout = 500; //.5 second

//PIN Definitions for Multiplexer
const int selectPins[3] = {2, 3, 4}; // S0~2, S1~3, S2~4
const int zInput = A5; // Connect common (Z)

const int NUM_OF_SENSORS = 8;
const int NUM_ON_MUX = 3;
int readings[NUM_OF_SENSORS];

void setup() {
  // initialize the serial port
  Serial.begin(9600);

  //Set select pins to output
  for (int i=0; i<3; i++)
  {
    pinMode(selectPins[i], OUTPUT);
    digitalWrite(selectPins[i], HIGH);
  }

  //set z input
  pinMode(zInput, INPUT);
}

void loop() {
  if(!isConnected){
    //checks to see if serial data is available to read
    if (Serial.available() > 0){
      incomingMessage = Serial.readStringUntil('\n');
      incomingMessage.trim();
  
      if(incomingMessage == "WakeUp"){
        Serial.println("ArduinoUno");
        isConnected = true;
        timeSinceLastReading = 0;
        delay(loopDelay);
      }
    }
  }
  else{
    timeSinceLastReading += loopDelay;
    if(timeSinceLastReading >= connectionTimeout){
      isConnected = false;
      return;
    }
    
    if (Serial.available() > 0){
      incomingMessage = Serial.readStringUntil('\n');
      incomingMessage.trim();
  
      if(incomingMessage == "reading"){
        timeSinceLastReading = 0;
      }
      else if(incomingMessage == "WakeUp"){
        Serial.println("ArduinoUno");
        isConnected = true;
        timeSinceLastReading = 0;
        delay(loopDelay);
        return;
      }
    }
    
    //read values and store in array
    //First, get values from sensors connected to analog pins directly
    // For example if you have NUM_OF_SENSORS=8, NUM_ON_MUX=3, this loop will iterate A0-A4
    // or if you had NUM_OF_SENSORS=5, NUM_ON_MUX=0, it would still iterate A0-A4, and no mux readings necessary
    for(int i = 0; i < NUM_OF_SENSORS - NUM_ON_MUX; i++){
      readings[i] = analogRead(i);
    }
    //Second, get mux readings
    int currentReading = NUM_OF_SENSORS - NUM_ON_MUX;
    for(byte pin = 0; pin < NUM_ON_MUX; pin++){
      selectMuxPin(pin); //enable select pins accordingly
      readings[currentReading] = analogRead(A5); // and read from Z
      currentReading++;
    }
  
    //create comma separated message to transmit over serial
    for(int i = 0; i < NUM_OF_SENSORS; i++){
      readingsMessage += String(readings[i]) + ",";
    }
  
    //print message to serial port
    Serial.println(readingsMessage);
  
    //reset message string
    readingsMessage = "";

    Serial.flush();
    delay(loopDelay);
  }
}


void selectMuxPin(byte pin)
{
  for (int i=0; i<3; i++)
  {
    if (pin & (1<<i))
      digitalWrite(selectPins[i], HIGH);
    else
      digitalWrite(selectPins[i], LOW);
  }
}

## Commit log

2020-06-04 created sensorsPrintTest program to test all sensors and print, comments added to sensorSerialWriter
2020-06-05 Five sensor serial writer is working. Still need to parse in unity SerialReader
2020-06-06 ParseMessage function implemented (store sensor readings in integer array.
2020-06-13 Fixed unity ReadLine() blocking bug. Moving a single object using a sensor
2020-06-13 Updated unity scene and script. Basic cube movement based on sensors.
2020-06-27 Add files via upload
    Only the calibration buttons have functionality so far, and there is an error when clicking both in a single run through
2020-06-30 bugfix: error when stopping and starting the software quickly
    [main.ino]
2020-07-08 Implementing of reconnection functionality in the case of the user disconnecting the controller during application runtime.
2020-07-08 Implementing of reconnection functionality in the case of the user disconnecting the controller during application runtime (2)
2020-07-22 Implemented multiplexer into arduino code for more sensor readings. NOTE: NUM_OF_SENSORS const is now updated to 8 in both the arduino main code and HFController class
2020-07-22 added eightSensorTest arduino sketch
2020-07-31 added pianoSim assets, including the mainscreen scene. MainScreen scene buttons configured to load the other scenes.
2020-08-01 Edited calibration script to close the port after calibration edit to build settings.
2020-08-01 bug fix regarding comma. and some fix for MacOS
    bug fix, MacOS compatibility, and also added Ironpython std. lib. for executing the file in MacOS.
    [GetCommand.py, executionfile.py]
2020-08-01 Removed the option for Alt
    Removed the option for Alt button. Because it didnt work in MacOS.
2020-08-03 Implemented calibration in FPS. Port is programmatically assigned in keyboard sim now
2020-08-04 3 extra sensors, new portname.txt file, back to main screen
    Added functionality for 3 extra sensors. the port name is saved in portname.txt file. Added a UI button and a function copied from the calibration.cs for going back to main screen. ToDo: test the 3 s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
2020-08-04 read from portname.txt, added 3 extra sensors, exit functionality
    GetCommands reads from a different file and saves it to a string (portName). Added 3 Extra sensors. changed the NUMBER_OF_SENSORS to 8. And when all 8 sensors are pressed the code will break out of t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
2020-08-04 UI buttons for 3 Extra sensors, back button
    UI buttons for 3 sensors left palm, right palm, top palm. back button for going back to the mainscreen.
2020-08-05 Keyboard bugfixes and some MainScreen scene edits before final demo vid recording
    [sensorCommands.py]
